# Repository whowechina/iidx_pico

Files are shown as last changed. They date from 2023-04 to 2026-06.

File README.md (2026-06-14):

# IIDX Pico - Beatmania IIDX Style Mini Controller
[点这里可以切换到中文版](README_CN.md)

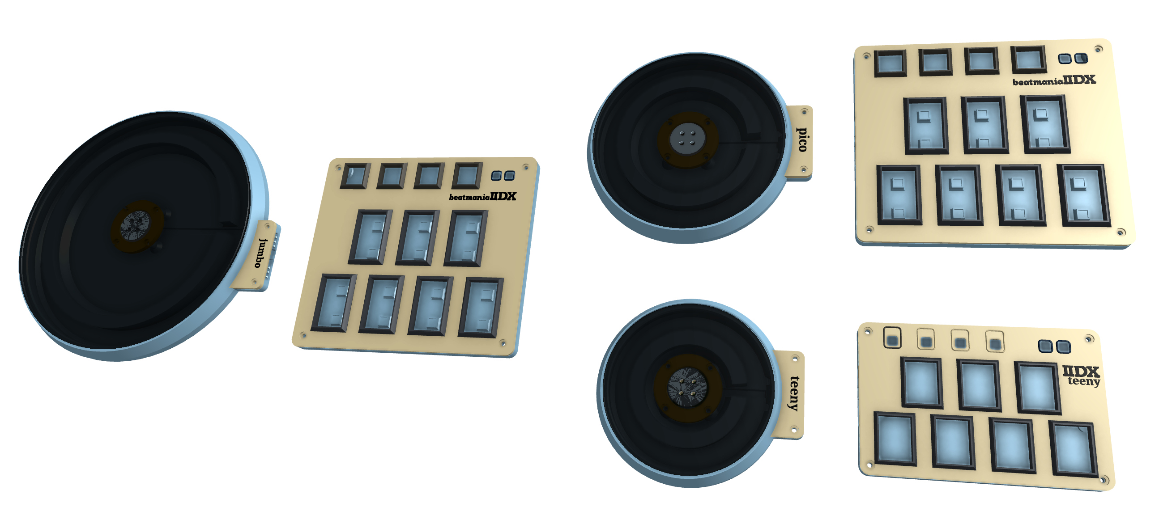
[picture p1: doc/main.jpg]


## Features
* Cool thin design.
* Many variants: IIDX Pico, IIDX Teeny, IIDX Jumbo and IIDX Itsy.
* Foldable with soft hinge.
* Now supports both Hall effect switches and mechanical switches.
* Customizable lights and effects.
* HID lights.
* IIDX Visa card holder.
* All source files open.

## Change Notes
* All IIDX Pico variants have been integrated into this repository for better management.
* The old IIDX Teeny repository has been archived and will be no longer updated.
* Old files have been moved to the Gen1Archive directory, but can also be found in the historical versions.

## Thanks
Thanks to many respectful guys/companies who made their tools or materials free or open source (KiCad, OnShape, InkScape, Raspberry things).

Special thanks to community projects and developers.
And also these projects:
* RP_Silicon_KiCad: https://github.com/HeadBoffin/RP_Silicon_KiCad
* Type-C: https://github.com/ai03-2725/Type-C.pretty

## My Other Projects
You can check out my other cool projects.

               


* Popn Pico: https://github.com/whowechina/popn_pico
* IIDX Pico: https://github.com/whowechina/iidx_pico
* Chu Pico: https://github.com/whowechina/chu_pico
* Mai Pico: https://github.com/whowechina/mai_pico
* Diva Pico: https://github.com/whowechina/diva_pico
* AIC Pico: https://github.com/whowechina/aic_pico
* Groove Pico: https://github.com/whowechina/groove_pico
* Geki Pico: https://github.com/whowechina/geki_pico
* Musec Pico: https://github.com/whowechina/musec_pico
* Ju Pico: https://github.com/whowechina/ju_pico
* Bishi Pico: https://github.com/whowechina/bishi_pico
* Nos Pico: https://github.com/whowechina/nos_pico
* Voltex Pico: https://github.com/whowechina/voltex_pico
* Chord Pico: https://github.com/whowechina/chord_pico
* Dance Pico: https://github.com/whowechina/dance_pico
* Arcade Pico: https://github.com/whowechina/arcade_pico

## **Disclaimer** ##
I made this project in my personal time with no financial benefit or sponsorship. I will continue to improve the project. I have done my best to ensure that everything is accurate and functional, there's always a chance that mistakes may occur. I cannot be held responsible for any loss of your time or money that may result from using this open source project. Thank you for your understanding.

## About the License
It's CC-NC. So DIY for yourself and for your friend, don't make money from it. And plagiarism that doesn’t even dare to mention the original author is not acceptable. Please note that pooling orders and group buying for raw materials is acceptable.Selling any leftover components at cost (without profit) is also acceptable.

If you're interested in buying from me, or for commercial use, please contact me (Discord, QQ group, Goofish).
* My Discord Invitation: https://discord.gg/M8f2PPQFEA
* QQ Group: 854535476
* Goofish: whowe12345

## HOW TO BUILD
### Turntable Materials
* 1x 5mm\*2mm magnet (must be radially magnetized).
* 1x 61804-2RS deep groove ball bearing (20x32x7mm), just choose the cheaper ones.
* 2x 6705-2RS (alternative) deep groove ball bearings (25x32x4mm) for IIDX Jumbo, less wobbling.
* 1x WS2812B LED strip. Go with ones with dense LED configurations. I recommend 80 LEDs per meter or higher for IIDX Pico and IIDX Jumbo; 120 LEDs per meter or higher for IIDX Teeny;
* 1x M2.5*6 screw and hex nut, to fix disc seat, magnet seat and bearing together.
* 4x M3*8mm screws, to fix bearing seat to the base.
* 4x M3*12mm screws, for the disc. 
* 2x M3*8mm screws and hex nuts, for the banner.
* 1x Custom cut black acrylic disc, 3mm thickness for IIDX Pico and IIDX Jumbo.
* Some 10mm non slip self-adhesive silicon pads (also for Keyboard).
* Silicone tube, inner diameter 25mm, outer diameter 27mm, serves as a hinge.
* Some soft ribbon cable with 7 wires, silicone 28AWG is recommended.
* Some acetate cloth tape helps to fix the wires.

### PCB and Keyboard Materials
* 1x Raspberry Pi Pico. If you're building the Itsy, use the "Supermini RP2040 Zero" module instead - it looks like the RP2040 Zero, but has components only on top side.  
  https://www.raspberrypi.com/products/raspberry-pi-pico
* 11x Kailh Choc v1 or v2 key switches, I suggest using linear switches for the 7 main buttons.  
  https://www.kailhswitch.com/mechanical-keyboard-switches/low-profile-key-switches/burnt-orange-switch.html  
  https://www.kailhswitch.com/mechanical-keyboard-switches/key-switches/kailh-low-profile-switch-choc-v2.html
* 7x Kailh 2.0U low-profile stabilizers.  
  https://chosfox.com/products/kailh-1350-choc-switch-6-25u-stabilizer-set
* 2x Panasonic EVQP1K05M square tactile switches for IIDX Pico and IIDX Jumbo.  
  https://www3.panasonic.biz/ac/e/dl/catalog/index.jsp?series_cd=3473&part_no=EVQP1K05M
* 6x Panasonic EVQP1K05M or ALPS SKPMAPE010 square tactile switches for IIDX Teeny.  
  https://www3.panasonic.biz/ac/e/dl/catalog/index.jsp?series_cd=3473&part_no=EVQP1K05M  
  https://tech.alpsalpine.com/e/products/detail/SKPMAPE010/
* 1x USB Type-C socket (918-418K2023S40001 or KH-TYPE-C-16P)
* 1x AS5600 (SOP8), MT6701CT-STD (SOP8), or TMAG5273 (SOT23-6) hall angular sensor chip. For MT6701, trim pin 8 (Z/CSN) if JP1 is not present on the PCB; for AS5600, solder bridge JP1 if it is present.
* RGB LEDs
  * IIDX Pico and IIDX Jumbo (nicer light effect version)
    * 28x WS2812B-1516 or WS2812B-2020 for main buttons, pinout should be exactly like this:  
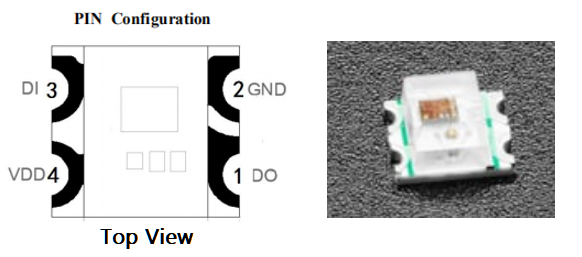
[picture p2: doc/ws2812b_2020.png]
      
    * 4x WS2812B-3528 (or WS2812B-2835), for AUX buttons.
  * IIDX Pico and IIDX Jumbo (easier soldering version)
    * 11x WS2812B-3528 (or WS2812B-2835), forget about ridiculously tiny 28x LEDs.
  * IIDX Teeny
    * 18 WS2812B-3528 (or WS2812B-2835).
* 4x 0603 5.1kohm resistors for USB and I2C.
* 6x 0603 0.1uF capacitors for IIDX Pico and IIDX Jumbo, 4x for IIDX Teeny.
* 4x Kailh low-profile keycaps for IIDX Pico and IIDX Jumbo.
* 4x M3*8mm screws and hex nuts to fix parts together.

### If you want to build Hall Effect version
* WS2812B-3528 per switch is no longer an option. Because it conflicts with the pinout.
* 1x ADG708BRUZ, 8 to 1 analog switch, in TSSOP-16 (U4).
* 1x LP5907MFX-4.5 or TPS7A2042PDBVR LDO, in SOT23-5 (U6), see next line.
* 1x LM4040 shunt voltage reference, get one with 2.0\~2.1V (for 4.2V LDO) or 2.2\~2.5V (for 4.5V LDO) reference voltage, in SOT23-3 (U5).
* 7x SS49E or compatible linear Hall Effect sensors, in SOT23-3 (H1-H7).
* 1x 10ohm resistor, 0603 (R5) and leave R6 absent.
* 1x 3.3V Zener diode, in SOD-123 or SOD-123F, such as BZT52H-C3V3 (Z1).
* 7x low profile magnetic switches, Gateron/NuPhy Jade Mini or Jade Pro Mini, Kailh Star Magnetic Mini, or compatible ones. (SW1-SW7).
* Some more 0.1uF capacitors. (All remaining capacitor positions).
* This shows the soldering for Hall Effect version.  
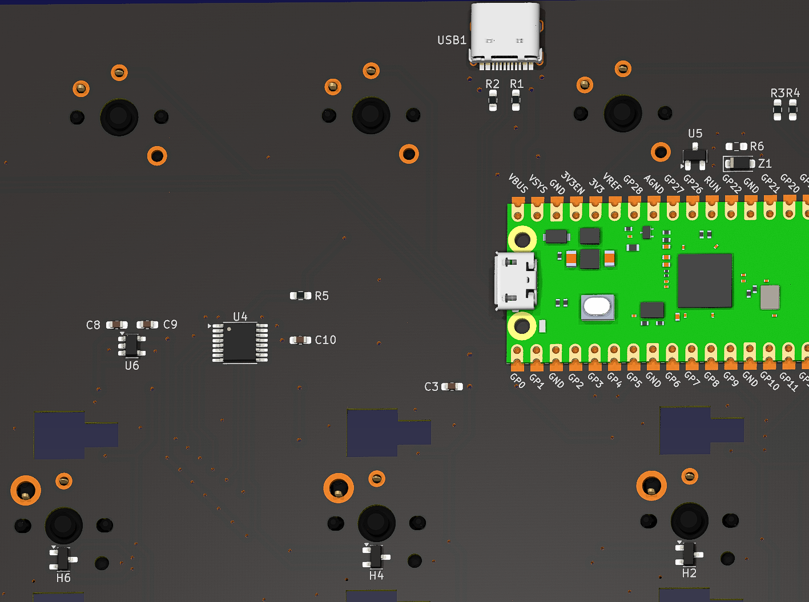
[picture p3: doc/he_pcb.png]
  

### Step 1 - Buy
* Main PCB  
  Just go [JLC](https://jlcpcb.com/) or some other PCB vendor you like and make the order. Make sure the board thickness is **1.2mm**, it's very important!
* Acrylic disc for IIDX Pico and IIDX Jumbo.  
  Find a vendor to cut a 3mm thick black acrylic using corresponding DXF file.  
  You can 3D print a turntable disc, but it is prone to heat deformation.

### Step 2 - 3D Print
#### Keyboard
For following prints, FDM, PLA, 0.4 nozzle, 0.2mm layer.
* Keyboard base ("Keyboard Base *.stl), PLA/PETG transparent, 2 to 3 walls.
* Keyboard panel ("Keyboard Panel.stl"), PLA/PETG transparent, 2 to 3 walls. Please render the panel art and text (height 3mm+) in black if you have multi-color printing system.

#### Turntable 
For following prints, FDM, PLA, 0.4 nozzle, 0.2mm layer, 3 to 4 walls.
* Base ("Turntable \* - Base.stl"), 20-40% infill.
* Bearing seat ("Turntable - Bearing Seat"), 40% to 60% infill.
* Magnet seat ("Turntable - Magnet Seat"), 40% to 60% infill.
* Disc seat ("Turntable - Disc Seat"), 40% to 60% infill.
* For IIDX Teeny only, the disc ("Turntable Teeny - Disc"), 80%+ infill, use a textured PEI bed and concentric pattern for a better surface.
* Banner ("Turntable * - Banner"), 20-40% infill. You can render the text in black if you have multi-color printing system.
* NOTE: IIDX Jumbo with 2 bearings is abbreviated as "Jumbo 2B" in the file name.

#### Button keycaps
* Keycap ("Keycap *.stl", choose the one matches your build), resin printing is recommended, but FDM can work in a pinch.

### Step 3 - Soldering and Assembly Tips
* Keyboard
  * It's very easy to miss two USB pins of the Raspberry Pico Pi, it's at the other side. It's difficult to solder as you may leave air bubbles in the soldering hole. Trick is to use sharpest iron tip, slowly apply solder wire.  
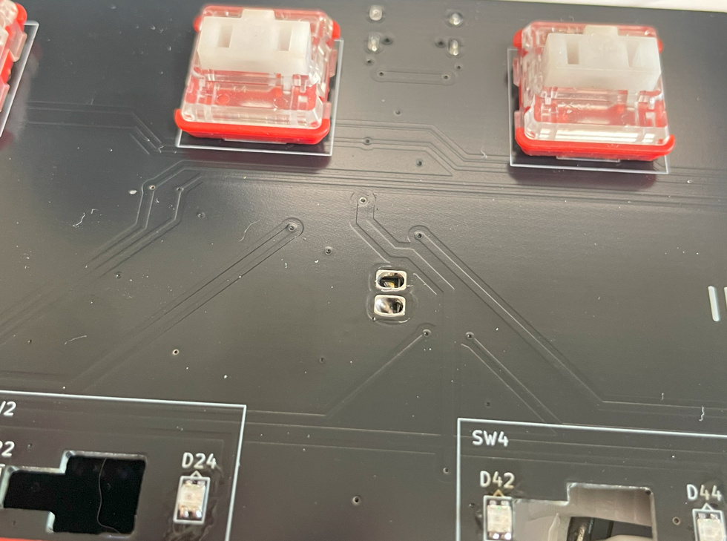
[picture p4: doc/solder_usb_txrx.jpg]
    
  * As long as you have Pi Pico soldered, you can upload firmware and test the board. Please test frequently during the soldering and assembly process.
  * There are two small sensor boards on the main PCB, one for AS5600, the other for TMAG5273. You only need one. After a successful test, you can snap it off for turntable assembly.
  * This gamepad test page can be used for testing. You can move a screwdriver bit on top of the AS5600 or TMAG5273 to see the axis movement.  
    https://greggman.github.io/html5-gamepad-test/
  * Install the low-profile stabilizers.  
    https://docs.keeb.io/choc-stabs  
    A little trick here. Since the PCB footprint is made to support both choc v1 and v2, that leaves some wobble space for choc v1 and making alignment more difficult. So leave the key switch unsoldered, when the stabilizer, the key switch and the keycap are all in place, push the keycap down and then solder the key switch. This way the key switch will be aligned to the stabilizers better.

* Turntable
  * Assembly is pretty straightforward.  
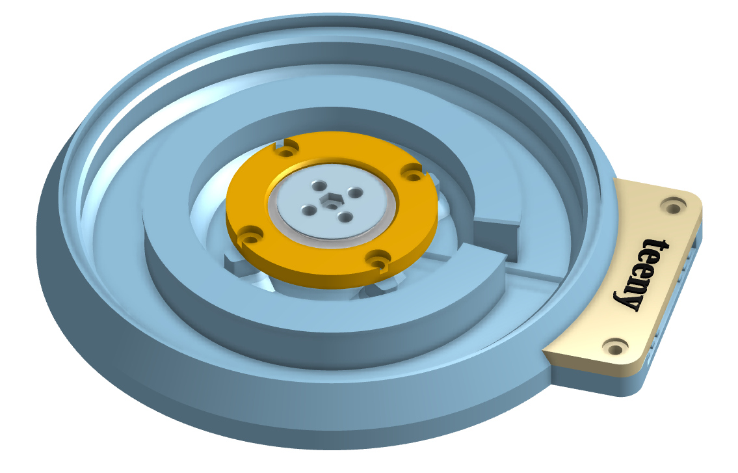
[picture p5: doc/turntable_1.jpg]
      
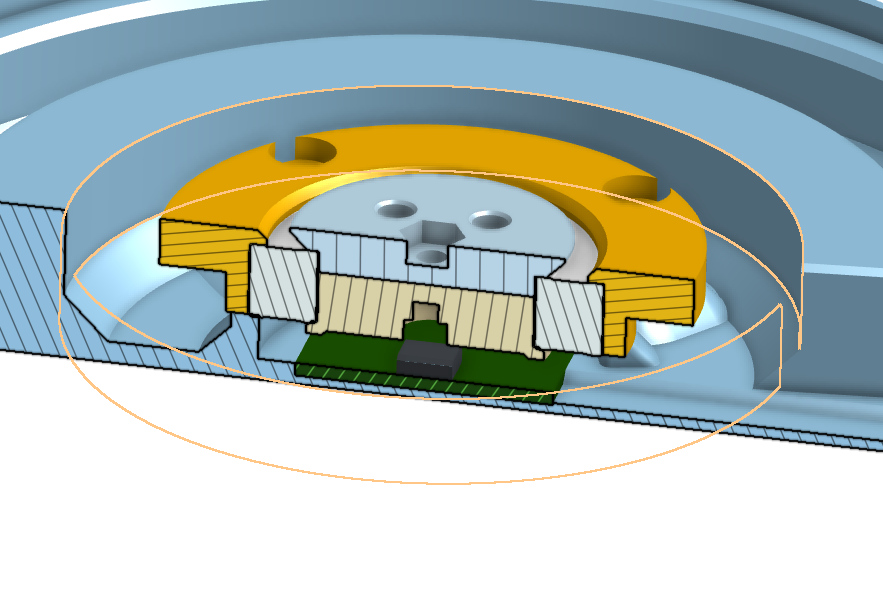
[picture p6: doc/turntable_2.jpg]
    
  * Sensor board is stuck to the base using some thin double-sided tape.
  * For IIDX Jumbo, two 6705-2RS bearings are stacked together.
  * Bearings are originally with very low friction, if you need more resistance, you can add some medium viscosity damping grease, but don't add too much. "2RS" in the bearing model means it's rubber sealed, it's easy to open the rubber seal and add grease.
  * RGB LED strip is stuck to the circular LED wall, both winding directions work.  
  * The 7-wire ribbon cable is for both the RGB LED and the sensor board, 3 for RGB LED, 4 for the sensor board.  
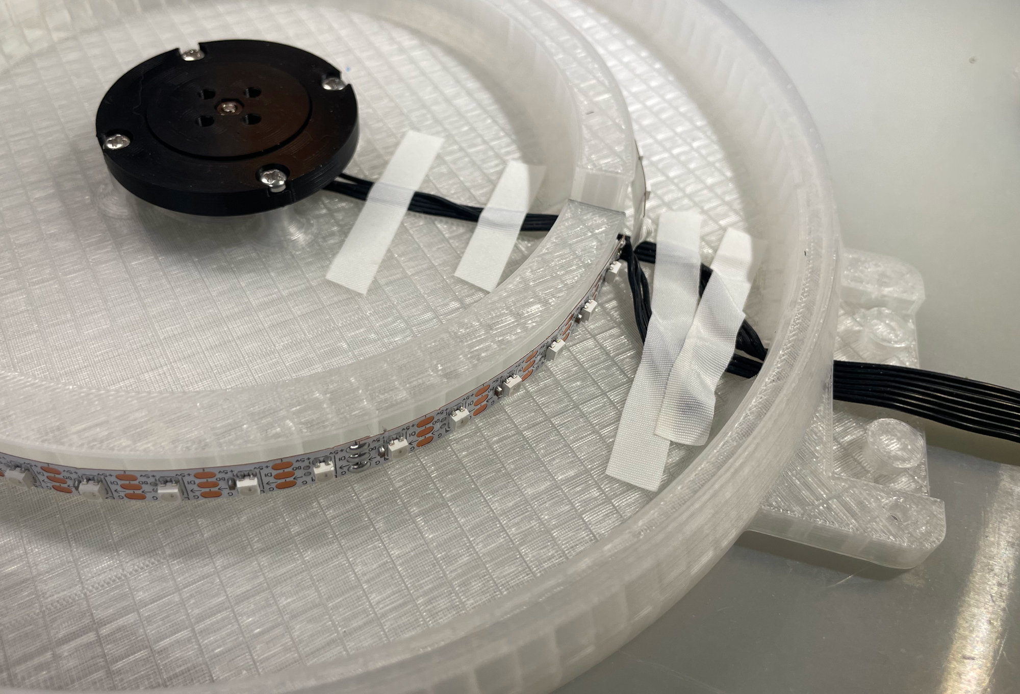
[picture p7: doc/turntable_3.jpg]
    
  * Silicone tube is to connect the turntable and the keyboard. Ribbon cable needs to go through the tube. You need a 7mm or 8mm hole punch to make holes on the silicone tube, to match the hooks at both turntable base and the keyboard sides.

### Notes on Hall Effect version
* For Kailh Star Mini, you need to use 704 RTV silicone adhesive to secure the magnetic switch to the PCB, to prevent it wobbling.
* Calibration must be done in the command line interface.
* Travel distance for triggering and reset can be configured only in the command line interface. They're stored in profile, which means, you can switch between different profiles and have different triggering settings for each profile.

### Firmware
* The UF2 file is in the `Production\Firmware` folder. IIDX Pico/Teeny/Jumbo share the same IIDX Pico firmware.
* For the new build, hold the BOOTSEL button while connect the USB to a PC, there will be a disk named "RPI-RP2" showed up. Drag the UF2 firmware binary file into it and that's it. There's a small hole at the back side of the keyboard, it is facing right to the BOOTSEL button.
* If it is already running my IIDX firmware, hold two small AUX buttons together will do the same as the BOOTSEL button.
* You need to setup your turntable LED strip first, check the manual for the SETUP mode.
* You can set the brightness, turntable LED theme, button LED theme.
* [Nice Looking Manual Here](doc/IIDX_Pico_Manual.pdf)  
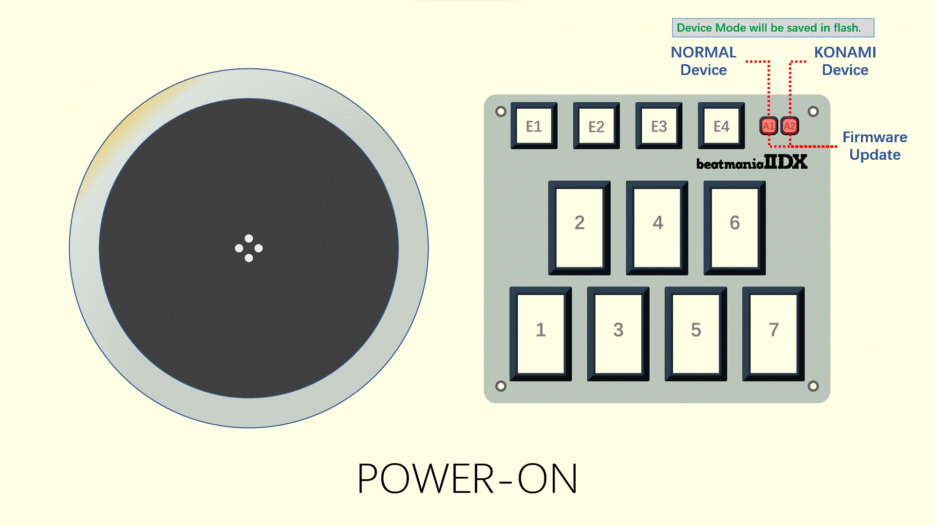
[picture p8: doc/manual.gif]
  

### Tools I Made
* Gamepad test - You can use it to check if all buttons and axes are working correctly.   
  https://whowechina.github.io/iidx_pico/Tools/gamepad_test.html
* Command-line tool - You can access controller's built-in CLI port using this tool.  
  https://whowechina.github.io/iidx_pico/Tools/cli_tool.html

### Bonus - IIDX Visa Card Holder
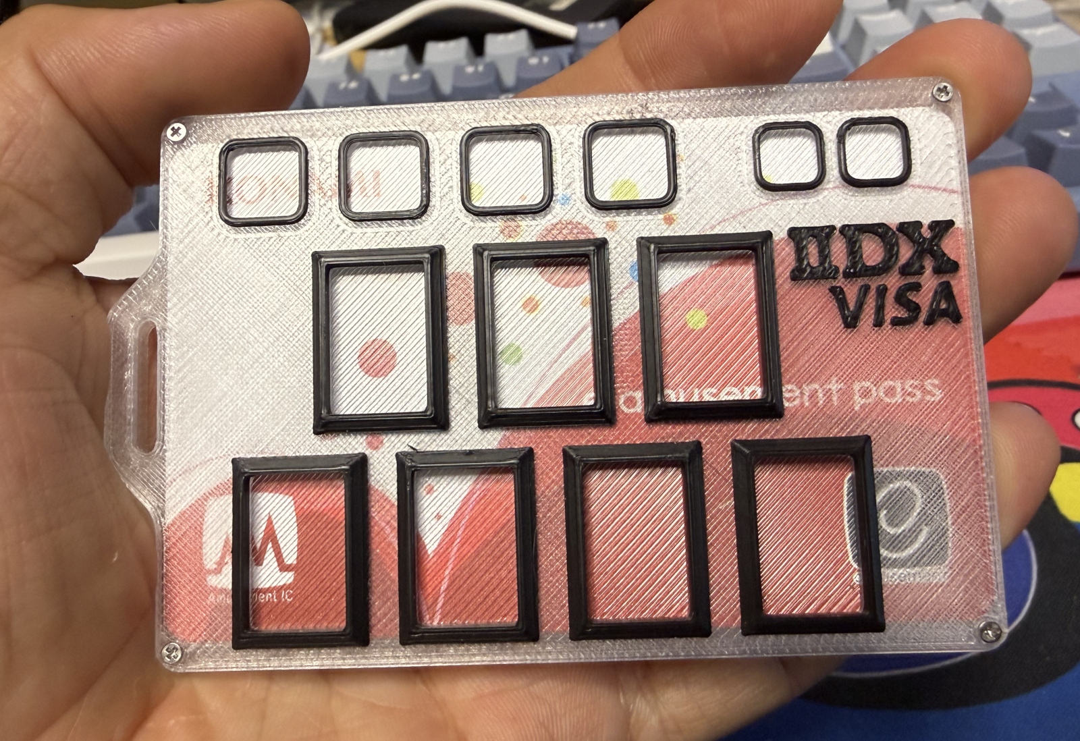
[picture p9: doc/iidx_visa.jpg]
   

* IIDX Visa card holder is a bonus design for IIDX Pico. It can be used to hold your credit card sized arcade cards.
* Print the base and the panel, assign different color for the pattern and text on the panel. `_insert` means it's the heat-set insert version. `_flat` means it's for flat head (countersunk) screws. Transparent material is recommended.
* If you choose the `_insert` version, use 4x M1.2\*1.5mm\*2mm (thread size\*length\*diameter) heat-set inserts on base part.
* 4x M1.2\*3mm screws to fix the panel and the base together. If you choose the `_flat` version, use M1.2\*3mm flat head screws.

## CAD Source File
I'm using OnShape free subscription. It's powerful but it can't archive original designs to local, so I can only share the link here. STL/DXF/DWG files are exported from this online document.  
https://cad.onshape.com/documents/ed99bfa5b4aec5d3ea6e6ed6/w/9a87f8b714078597b4ef5e3c/e/2e27bace5a421a921473c027

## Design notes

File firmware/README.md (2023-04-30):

# IIDX Pico Firmware

Features:
* 1000Hz polling rate.
* HID lights.
* RGB turntable.
* Configuration save.
* Customizable through board_defs.h
* Dymanic settings.

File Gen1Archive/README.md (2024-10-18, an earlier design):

# IIDX Pico - Beatmania IIDX controller

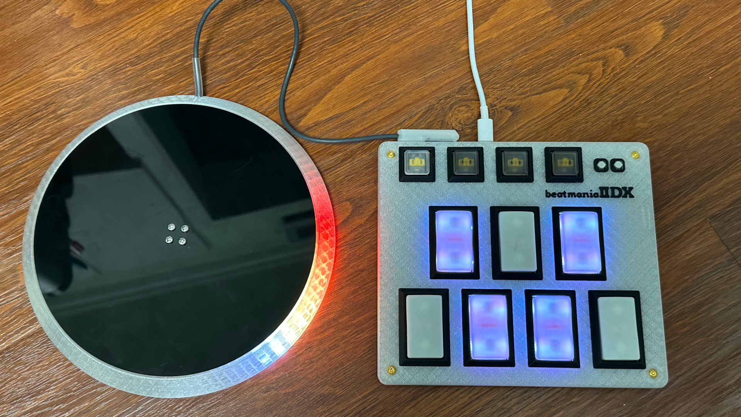
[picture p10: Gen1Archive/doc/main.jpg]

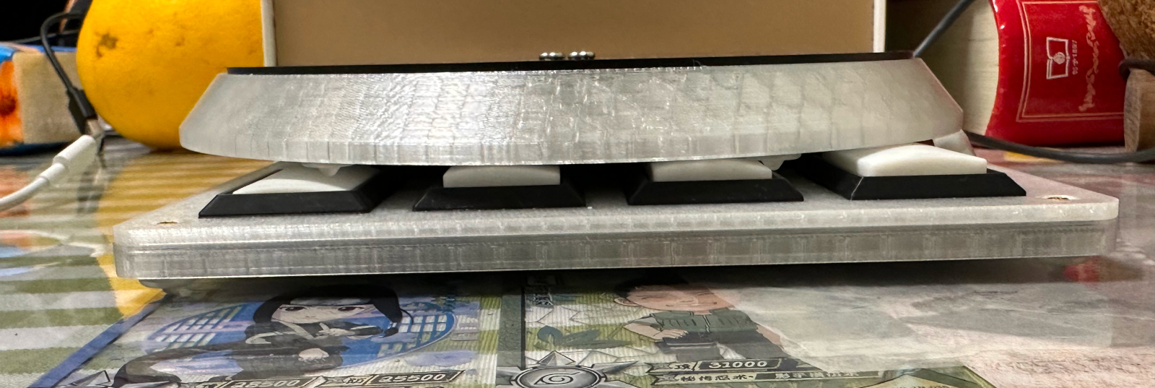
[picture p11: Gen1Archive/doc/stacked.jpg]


<video src="https://user-images.githubusercontent.com/11623830/229287886-d01893c5-04b6-41fc-a178-72c815e28c96.mp4" controls="controls" width="50%"></video>

Features:
* It's thin, really thin.
* Detachable turntable using magnetic connector (soft hinge is another option).
* HID lights, of course!
* Key color theme and customization.
* Multiple turntable effects.
* Many live settings.
* Konami device mode for IIDX Ultimate Mobile.
* All source files open.

Thanks to many respectful guys/companies who made their tools or materials free or open source (KiCad, OpenSCAD, InkScape, Raspberry things). And also:
* RP_Silicon_KiCad: https://github.com/HeadBoffin/RP_Silicon_KiCad
* Switch_Keyboard_Kailh: https://github.com/kiswitch/keyswitch-kicad-library
* Type-C: https://github.com/ai03-2725/Type-C.pretty

## Notes
This is a difficult build, it heavily depends on 3D printing, both FDM and SLA (resin). It also requires skills to solder tiny components and thin cables., much more difficult than my other projects such as Pico Popn.

Move forward only if you're REALLY interested.  

## My Other Projects
You can check out my other cool projects.

         

* Popn Pico: https://github.com/whowechina/popn_pico
* IIDX Pico: https://github.com/whowechina/iidx_pico
* IIDX Teeny: https://github.com/whowechina/iidx_teeny
* Chu Pico: https://github.com/whowechina/chu_pico
* Mai Pico: https://github.com/whowechina/mai_pico
* Diva Pico: https://github.com/whowechina/diva_pico
* AIC Pico: https://github.com/whowechina/aic_pico
* Groove Pico: https://github.com/whowechina/groove_pico
* Geki Pico: https://github.com/whowechina/geki_pico
* Musec Pico: https://github.com/whowechina/musec_pico

## **Disclaimer** ##
I made this project in my personal time with no financial benefit or sponsorship. I will continue to improve the project. I have done my best to ensure that everything is accurate and functional, there's always a chance that mistakes may occur. I cannot be held responsible for any loss of your time or money that may result from using this open source project. Thank you for your understanding.

## About the License
It's CC-NC. So DIY for yourself and for your friend, don't make money from it. And plagiarism that doesn’t even dare to mention the original author is not acceptable. Plase note that pooling orders and group buying for raw materials is acceptable. Selling off any leftover components without profit is also acceptable.

If you're interested in some kind of commercial use, please contact me (Discord, QQ group, Wechat group or leave your contact in issue section).

## My Discord Invitation
https://discord.gg/M8f2PPQFEA

## HOW TO BUILD
### Turntable Materials
* 1x AS5600 hall angular sensor board set (23mm\*23mm)  
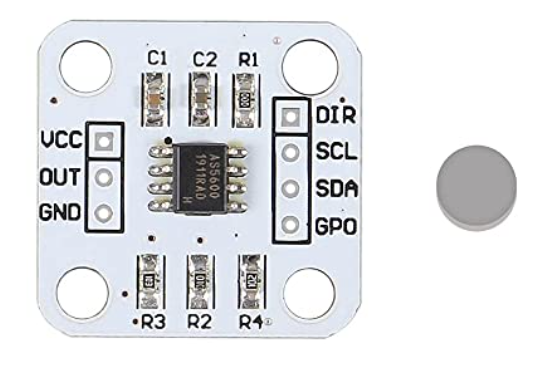
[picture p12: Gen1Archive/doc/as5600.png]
  
* 1x 6mm\*2mm magnet (must be radially magnetized), normally comes with the AS5600 board set.
* 1x 61804-2RS deep groove ball bearing (20x32x7mm), normally < 5US$;
* 1x WS2812B LED ring board, or RGB LED strip (recommended). Choose ones with dense LED arrangement (>=32 LEDs per board, or >90 LEDS per meter);
* 3x M4*10mm screws (large flat head is better) and hex nuts, for bearing. For hinge version, use M3 screws.
* 4x M3*12mm screws, for spinning disc. 
* 1x REF3030 (3.0V Voltage Reference, SOT-23-3).
* 1x Custom cut black acrylic disc, 4mm thickness.
* 11x 12mm non slip self-adhesive silicon pads (also for Keyboard).  
  https://www.amazon.com/Cabinet-Dampening-Adhesive-Circular-Stoppers/dp/B07XXWG818

### Keyboard Materials
* 1x Raspberry Pi Pico.  
  https://www.raspberrypi.com/products/raspberry-pi-pico
* 11x Kailh Choc v1 or v2 key switches, to get better play feel, 7 of them should be 50g linear.  
  https://www.kailhswitch.com/mechanical-keyboard-switches/low-profile-key-switches/burnt-orange-switch.html  
  https://www.kailhswitch.com/mechanical-keyboard-switches/key-switches/kailh-low-profile-switch-choc-v2.html
* 7x Kailh low-profile stabilizers.  
  https://chosfox.com/products/kailh-1350-choc-switch-6-25u-stabilizer-set
* 2x Panasonic 6mm square tactile switch EVQP1K05M.  
  https://www3.panasonic.biz/ac/e/dl/catalog/index.jsp?series_cd=3473&part_no=EVQP1K05M
* 1x USB Type-C socket (918-418K2023S40001 or KH-TYPE-C-16P)
* 11x WS2812B-3528 RGB LEDs or if you want more challenge: 28x WS2812B-1516.
* 2x SN74LV1T34DBVR (SOT-23-5) level shifter, optional, for better voltage tolerance.
* 2x 0603 10ohm resistors to bypass said level shifters, optional.
* 1x 0603 5.1kohm resistors for USB.
* 5x 0805 1uF capacitors.
* 4x Kailh low-profile keycaps.
* 4x M3*6mm screws and hex nuts to fix parts together.

### Detachable Cable
* 1x HDMI cable (ultra slim, diameter < 4mm), at least 50cm in length, we'll cut the HDMI connectors off, so pick a cheap one.
* 2X Magnetic pogopin connector sets, male and female. PCB side should use ones with 90-degree pins, cable side use ones with straight pins.  
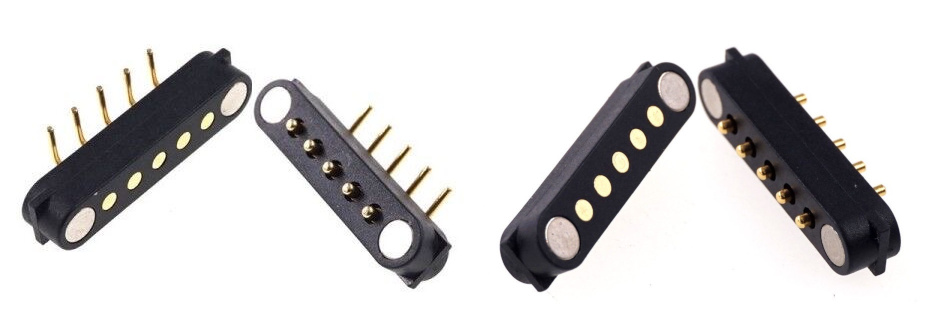
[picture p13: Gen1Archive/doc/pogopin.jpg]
  

### Step 1 - Buy
* Keyboard PCB  
  Just go [JLC](https://jlcpcb.com/) and make the order. Make sure the board thickness is **1.2mm**, it's very important!
* Turntable PCB  
  It's an optional one. It makes the wiring and soldering inside the turntable a litter easier.
* Acrylic disc  
  Choose the dxf file according to your disc size and find a vendor to cut the 4mm black acrylic.

### Step 2 - 3D Print
#### Keyboard
* PCB bottom (pcb_bottom_*.stl, choose one according to your connector or hinge choice)  
  FDM, PLA/PETG transparent, 0.2mm layer, 4 walls.
* PCB top (pcb_top.stl)  
  FDM, PLA transparent, 0.2mm layer, 4 walls.  
  If you have Bambu Lab's AMS system, use PLA black/gray for 3.0mm+ layers.

#### Turntable 
For following prints, FDM, PLA, 0.4 nozzle, 0.16-0.2mm layer, 4 walls.  And very important: "Seam Position" should be set to "**Random**" in your slicer, not only it looks better, it makes the bearing-flange coupling smoother and tension distributed more evenly.  
These are all printed with
* Base (TT_base_xxx.stl), choose one of the 150, 170 or 180, based on your choice of disc size, 20-60% fill.
* Bearing seat (bearing_seat_6804.stl), 20-60% fill.
* Flange for disc (TTshaft_6804.stl), 60% fill.
* If you opt for the hinge option, go with the files with "hinge" in the filename.

#### Pogopin Connector
It's very small and requires higher accuracy.
* Housing for pogopin connector (pogo_bottom.stl, pogo_top.stl).  
  FDM, PLA, **0.2 nozzle** is recommended, 0.1mm layer, 4 walls, 60% fill.

#### Button keycaps  
  * Option 1 (Choc V1 or V2): SLA (resin), regular white, 0.05mm layer, check out my orientation:  
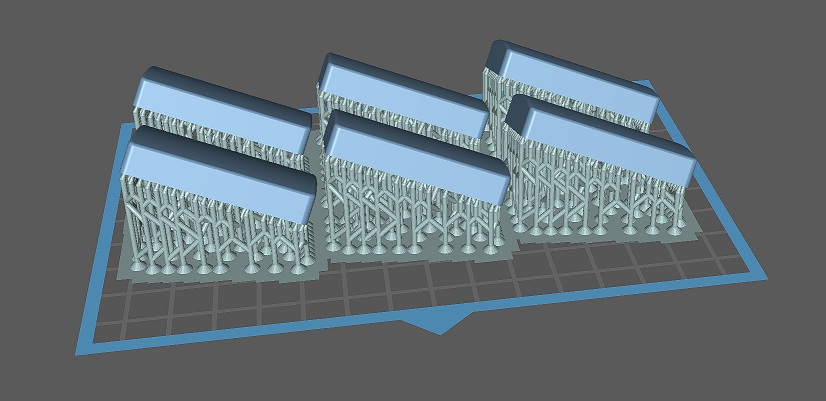
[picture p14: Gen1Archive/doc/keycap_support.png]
    
  * Option 2 (Choc V2 only): FDM, PLA white, 0.2mm nozzle recommended but 0.4mm nozzle works too, 0.10~0.16mm layer, use easy-to-remove material for support, like "Bambu Support W" or just PETG.  
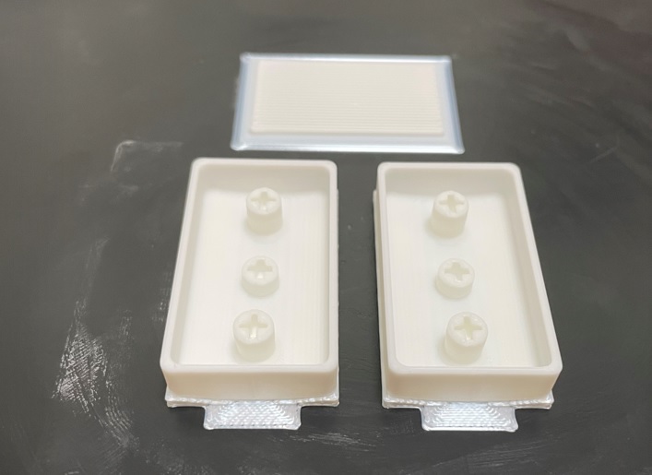
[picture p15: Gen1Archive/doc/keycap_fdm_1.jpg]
    
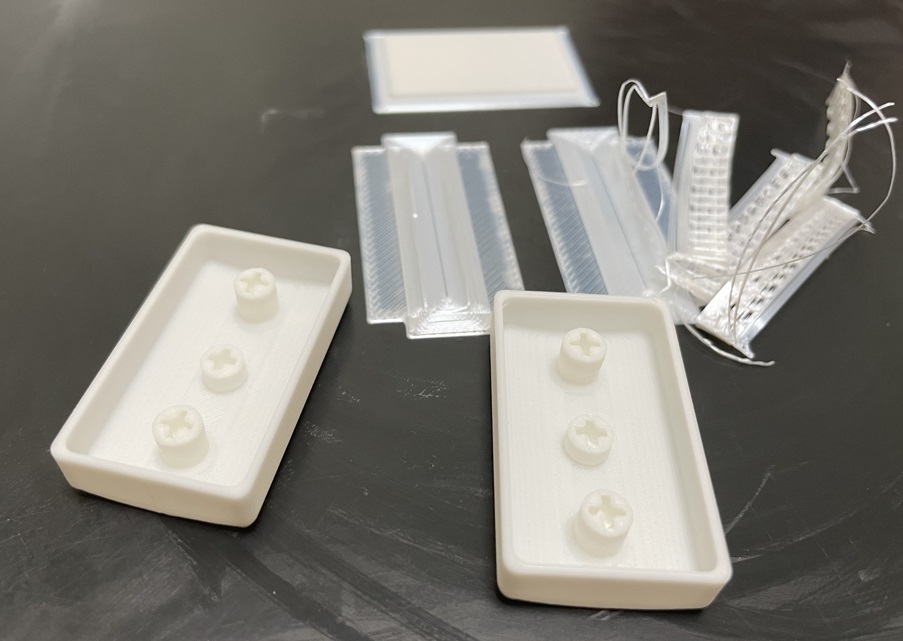
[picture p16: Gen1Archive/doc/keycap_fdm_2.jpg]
    

### Step 3 - Solder
* Keyboard  
  * WS2812 choices for main 7 main keys, for each key: solder 1x WS2812B-3528 under the key switch, or 4x WS2812-1516 around the key switch.
  * IMPORTANT: be careful about the orientation of LEDs, they're different at different rows or columns.  
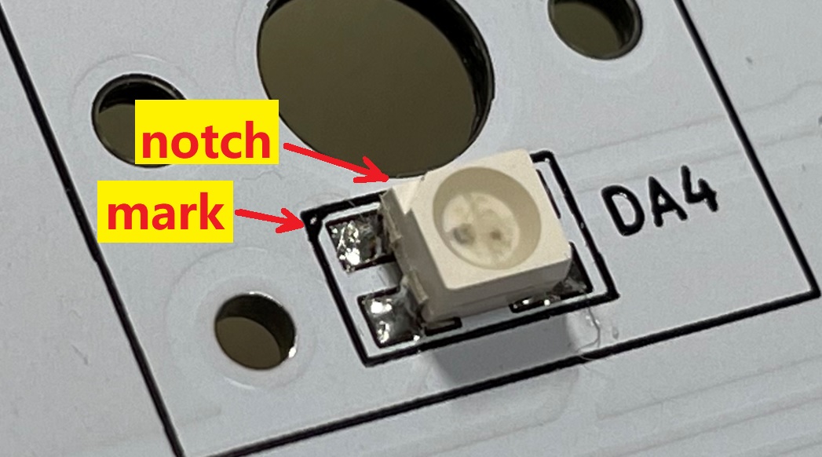
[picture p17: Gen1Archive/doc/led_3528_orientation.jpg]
    
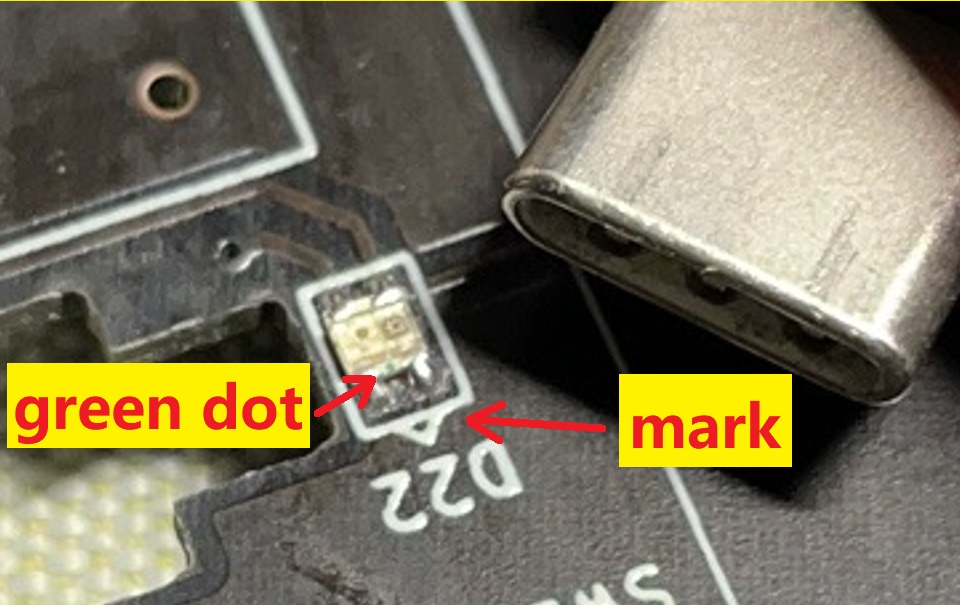
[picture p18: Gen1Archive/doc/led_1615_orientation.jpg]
    
  * Connector choices: solder 2x pogopin connectors, or solder 1x 3.5mm headphone input jack.
  * It's very easy to miss the USB pins of the Raspberry Pico Pi, it's at the other side. And it's difficult to solder as you may leave an airbubble in the soldering hole. My trick is to use sharpest iron tip, super-slowly apply solder wire only at one side. This is my result:  
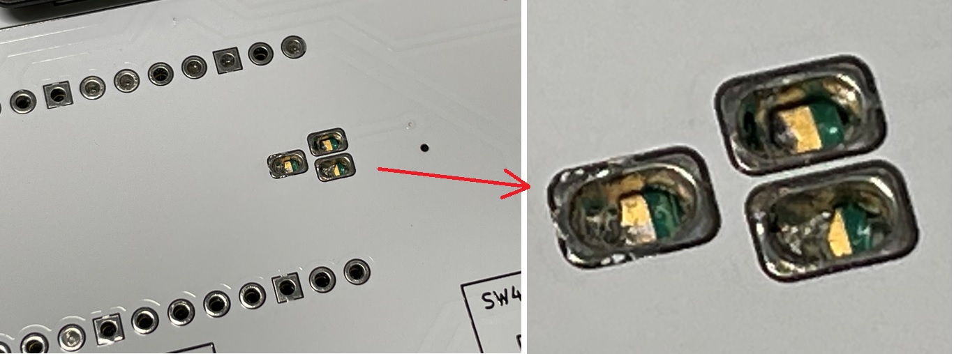
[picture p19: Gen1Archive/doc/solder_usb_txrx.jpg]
    

  * You can use level shifter (SN74LV1T34DBVR, U2/U3), or you can just bypass it by soldering a nearby resistor (10 ohm, R1/R2).
  * Optional: TVS1 and TVS2 are rated 3.3V, protecting GPIOs. TVS3 should be rated 5V when using level shifter, and 3.3V when not using level shifter.
* Turntable
  * General  
  Typical AS5600 development board comes with 3.3V configuration, we can't feed 5V to it directly, it would burn the AS5600 or the main Pi Pico. The GPIO we use to communicate with AS5600 can never go beyond 3.6V. So we need a lower voltage, I chose REF3030, a precise 3.0V voltage reference.  
  You need to scrape off some solder mask to expose the ground copper (don't scrape the solder mask under 5V pin). I found a good place to mount the REF3030, this is how I handled it:  
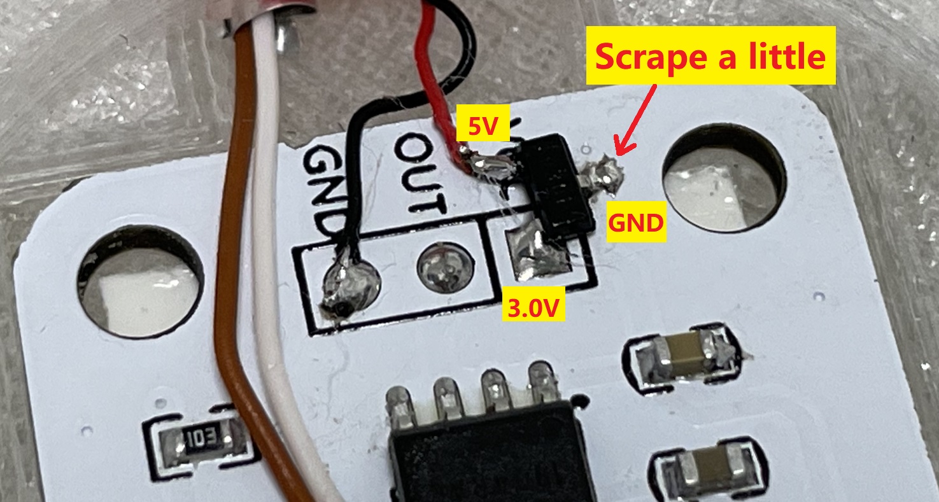
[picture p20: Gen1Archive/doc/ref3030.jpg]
    

  * **Very Important**  
  Before proceeding further, it's important to know that the silicone hinge option used in my IIDX Teeny has proven to be the most effective and stable. Therefore, it's highly recommended to opt for the hinge option, rather than the subsequent digital (pogopin). I've also removed the analog (3.5mm headphone jack) option simply because it's not good. If you use Teeny's silicone hinge option, use the added J3/J4 3.3v soldering pads to power the AS5600.

  * If you go with digital (magnetic pogo pin connector)  
  There're a set of I2C and a WS2812B signal line together in the cable that connects turntable and the keyboard. Unfortunately, these signals crosstalk. So, we have to use shield cables for them. Two I2C lines should have a shield cable, and the WS2812B signal should have another shield cable. Good thing is, an HDMI cable has 4 shield cables and bunch of other small cables. We can make use of it.  
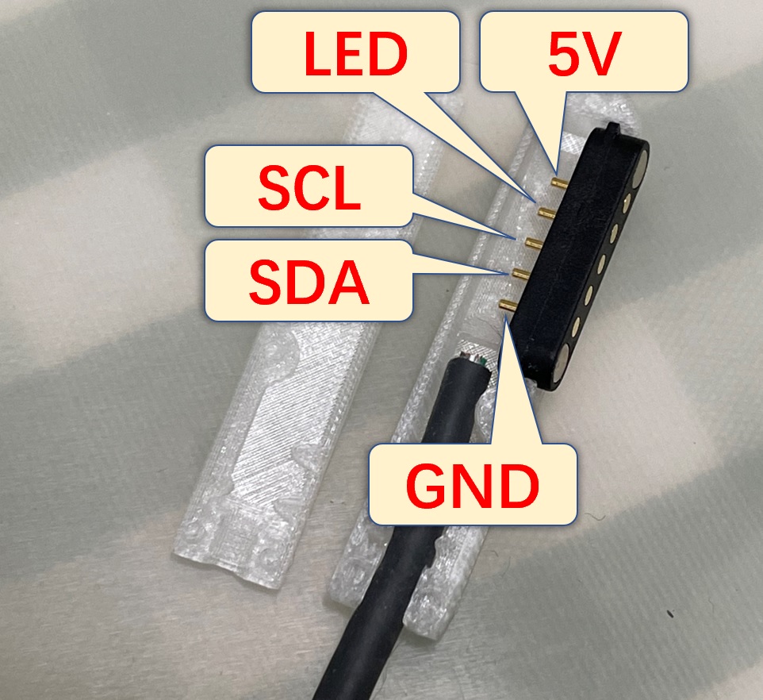
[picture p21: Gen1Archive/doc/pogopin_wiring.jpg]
      

* Turntable LED Ring  
  I recommend to use LED strip over LED board, becuase the LED board's light is facing up, but using strip, the light can spread out pefectly.  
  Use transparent double-sided tape to stick the LED around the turntable inner wall.

### Step 4 - Assemble
* Assemble the turntable  
  I don't know how to draw an explosion diagram, this is done by coding in OpenSCAD:  
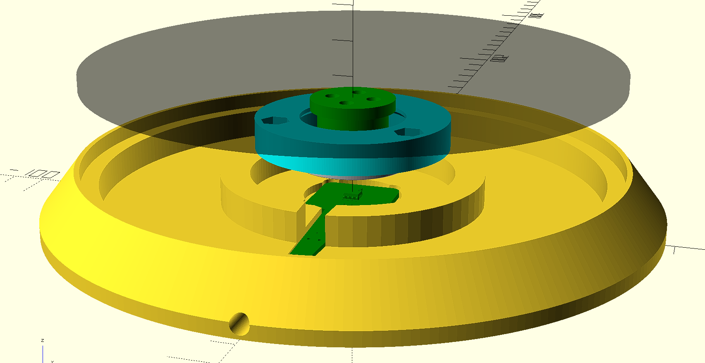
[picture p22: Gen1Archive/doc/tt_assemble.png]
    
  These shows how a bearing is installed.  
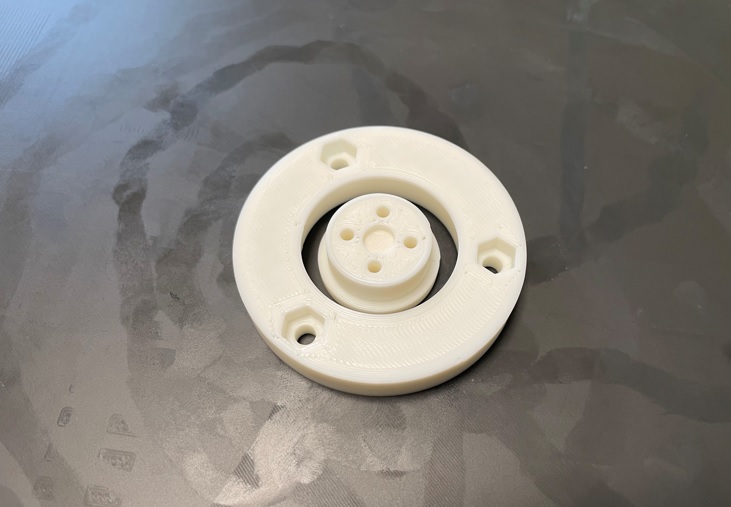
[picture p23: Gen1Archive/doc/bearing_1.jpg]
  
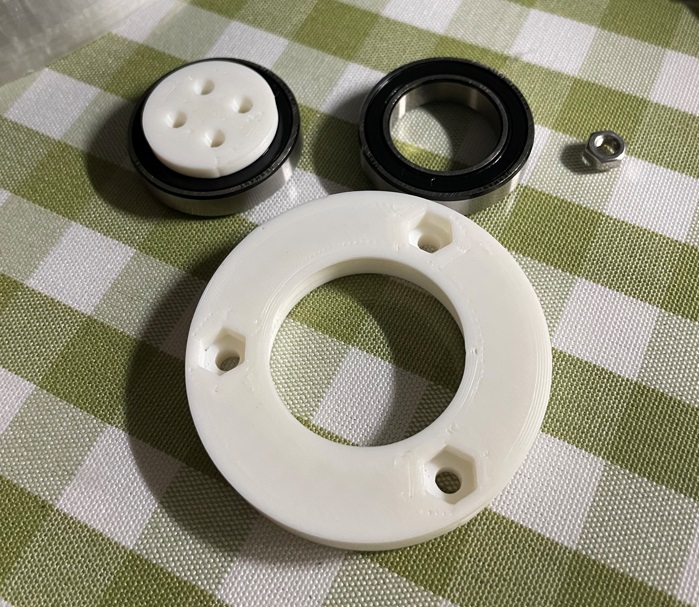
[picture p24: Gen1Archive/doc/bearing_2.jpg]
  
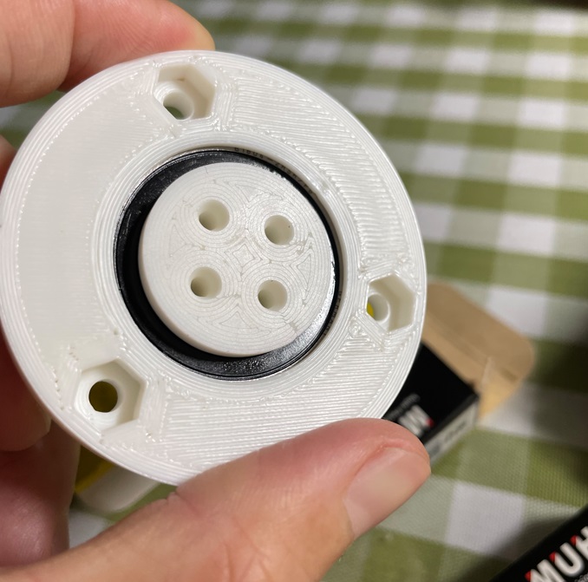
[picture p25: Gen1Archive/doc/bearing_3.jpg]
  
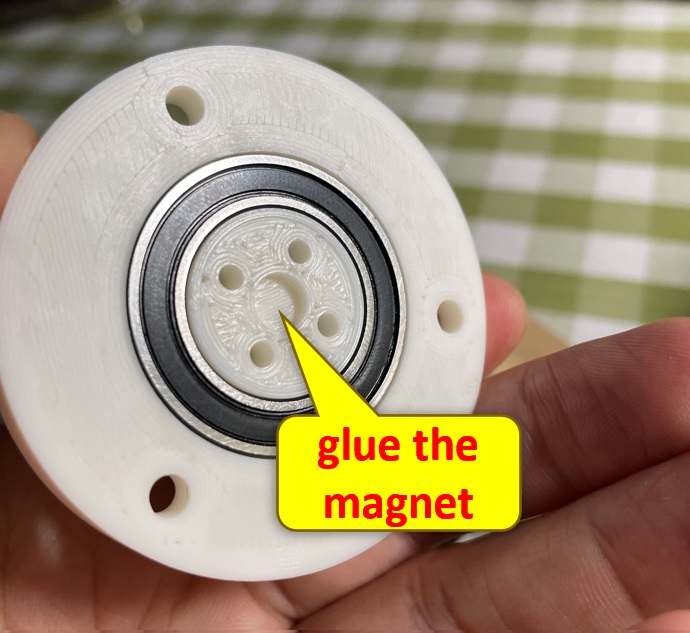
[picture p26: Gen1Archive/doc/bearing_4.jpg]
  
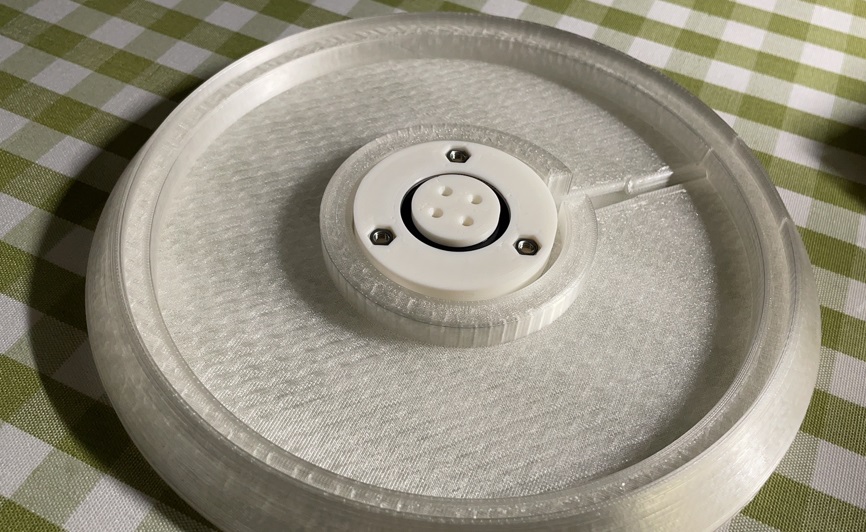
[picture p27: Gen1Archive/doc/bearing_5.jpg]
  

* Install the low-profile stabilizers.  
  https://docs.keeb.io/choc-stabs  
  A little trick here. As the PCB footprint is made to support both choc v1 and v2, that leaves some wobble space for choc v1 and makes it difficult to align. So leave the key switch unsoldered, when the stabilizer, the key switch and the keycap are all in place, push the keycap down and then solder the key switch. This way the key switch will be aligned to the stabilizers better.

  **VERY IMPORTANT**

  I made a terrible mistake in early PCBs which causes main buttons sticky (not physically responsive as expected). If you're using PCB v1.3 or later version, you're fine. If you're using PCB v1.2 or earlier version, there's a simple fix. Just manually cut some bevelling on the PCB, so stabilizer's shaft can move freely. You need to do all the buttons. Please don't cut through the PCB, just cut the edge a little at the bottom.  
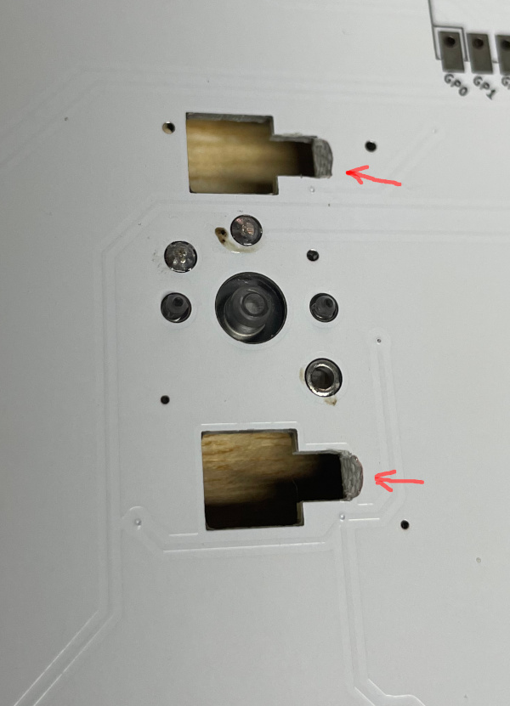
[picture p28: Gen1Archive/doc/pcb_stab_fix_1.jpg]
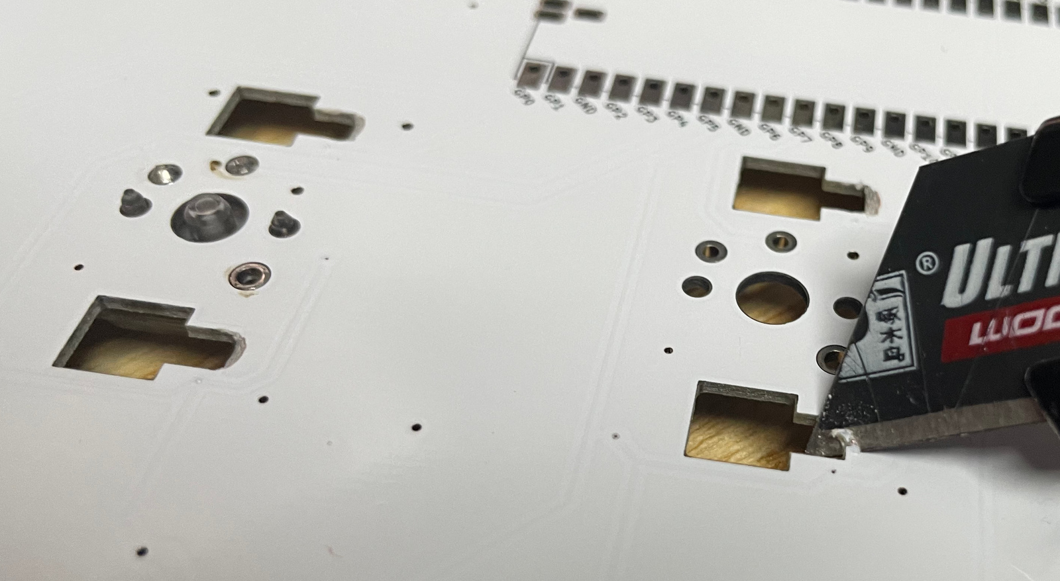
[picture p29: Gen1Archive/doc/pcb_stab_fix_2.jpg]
   

* Assemble the keyboard  
  It's very easy.  
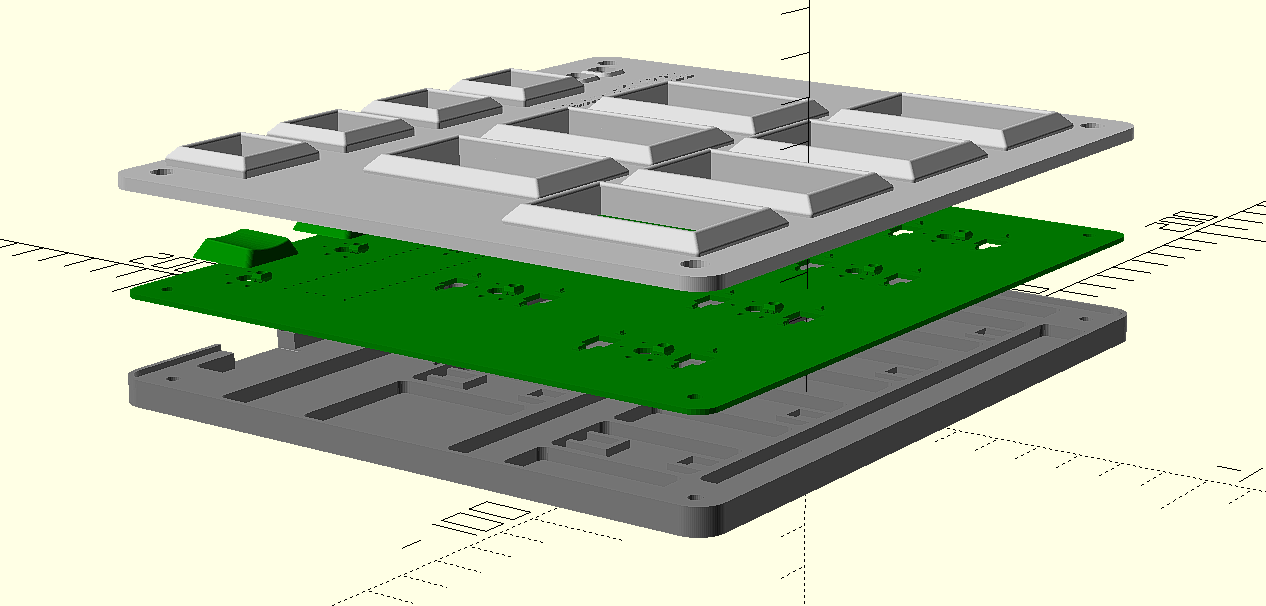
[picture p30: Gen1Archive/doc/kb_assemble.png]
    
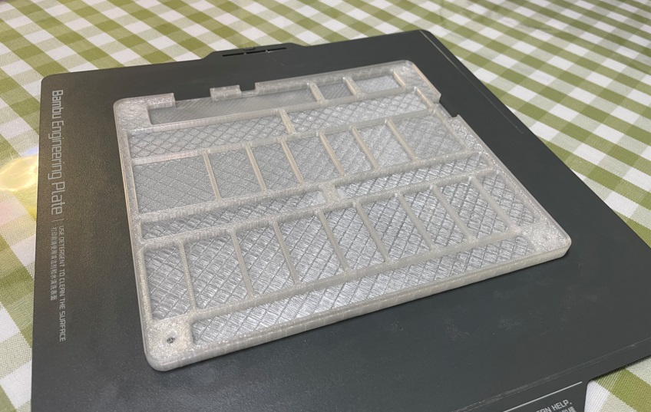
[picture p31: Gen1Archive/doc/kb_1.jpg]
  
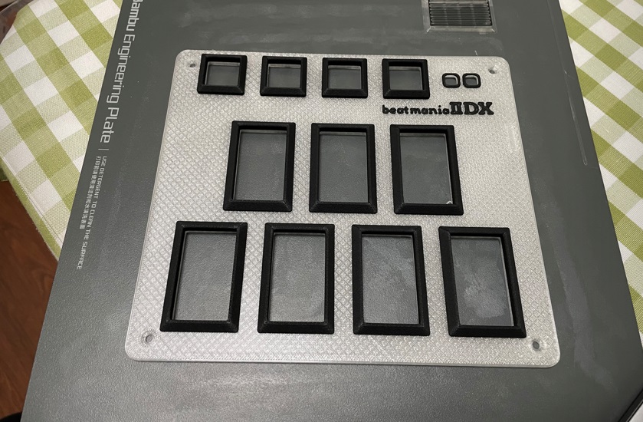
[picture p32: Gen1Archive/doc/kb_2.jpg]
  
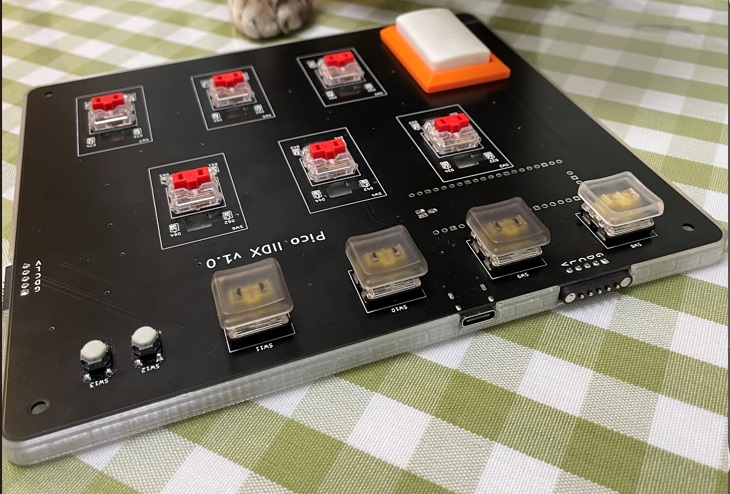
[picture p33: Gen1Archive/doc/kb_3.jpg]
  
  
  

### Step 4 - Firmware
* For the new build, hold the BOOTSEL button while connect the USB to a PC, there will be a disk named "RPI-RP2" showed up. Drag the uf2 firmware binary file into it. That's it. There's a small hole at the back side of the keyboard, it is facing right to the BOOTSEL button.
* If it is already running my IIDX firmware, hold two small AUX buttons together will do the same as the BOOTSEL button.
* You need to setup your configuration such as AS5600 connection mode and LED ring.
* Also you can setup the key color theme and turntable effects at runtime. I think I made the configuration too showey and complicated. Check out the manual.   
  [Nice Looking Manual Here](doc/Firmware_manual.pdf)
  

### What If?
* I can't find pogopin connector.  
**Solution:** I figured out some another choices, one is using a 3.5mm 4P headphone jack. It uses analog to communicate turntable movements, but I'm still testing it, so stay tuned. I will update this document. The other is to use fixed connection (left or right hinge).
* I don't have Bambu Lab's machine, or I don't have an AMS system.  
**Solution:** There're many online vendors and people providing paid Bambu printing service. Or you can just use other 3D printers. It's just the numbers in the OpenSCAD source file or STL files are finetuned on my Bambu Lab X1. You may need to adjust a little on your 3D printer system to get perfect result. And regarding the multi-color thing, maybe you can just paint the top layer by hand. I know people do miniature painting, I think it would be similar.
* STL files are not accurate, difficult to assemble.  
**Solution:** 3D printer systems are different one from another, it results in small differences even with same model file and some configuration. If the printed parts are not happy with each other, you can fiddle with the OpenSCAD source file and the numbers in it for your case.
* I don't have resin printer.
* I can't find Kailh low-profile stabilizer.
* I don't have electronic DIY gears.  
**Solution:** OK, this is an electronic hobby project, maybe it's not for you if you don't plan to do electronic DIYs. There're many good IIDX controllers you can purchase somewhere online.
* I want Bluetooth support.  
**Not A Solution:** I once wanted to implement the Bluetooth support. But after I tried bluetooth joystick, I gave up. You really don't want to play rhythm game with a Bluetooth connection!

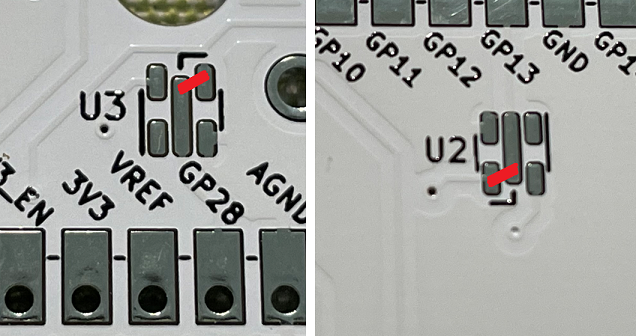
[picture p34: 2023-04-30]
doc/bypass_level_shifter.png

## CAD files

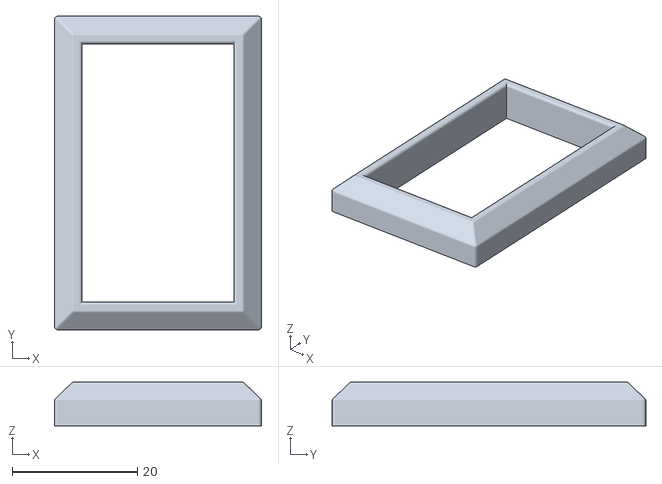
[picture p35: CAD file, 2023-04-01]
cad/keycap_frame_main.stl
33.0 x 50.0 x 7.00

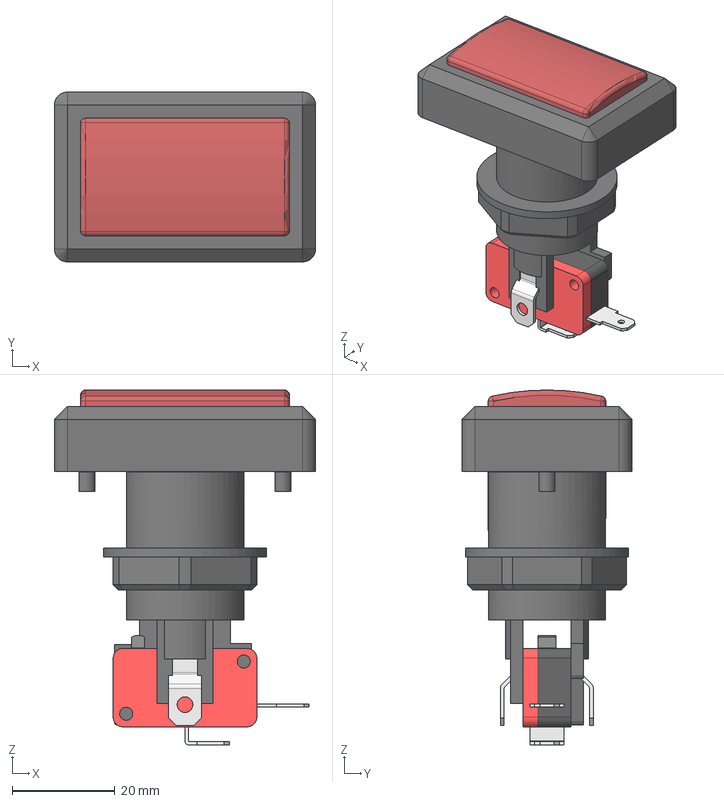
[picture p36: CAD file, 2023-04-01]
PCB/Itsy/3dmodels/Credit Button Assy (Groovy).step
50.8 x 33.0 x 69.0 mm
Button
Nut
Switch

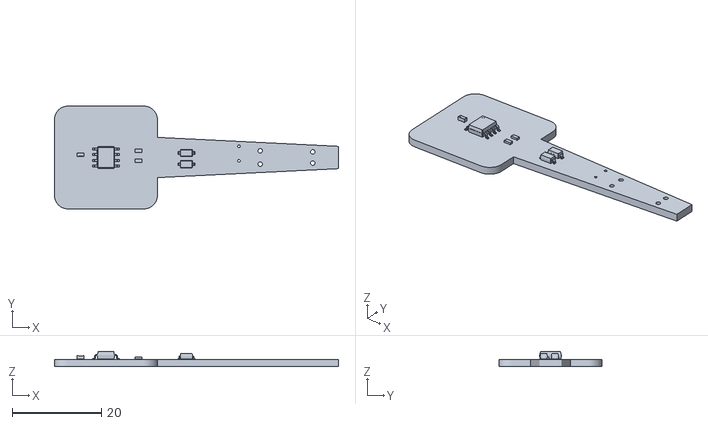
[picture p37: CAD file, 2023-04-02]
cad/iidx_tt v1.stl
63.5 x 23.0 x 3.40

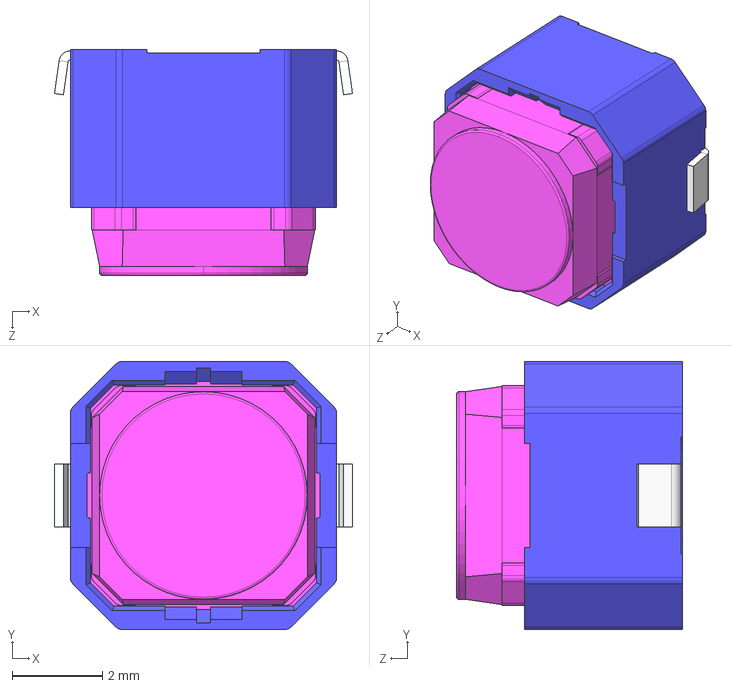
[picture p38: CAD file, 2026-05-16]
PCB/Itsy/3dmodels/SKPMAM.STEP
6.60 x 5.94 x 5.00 mm

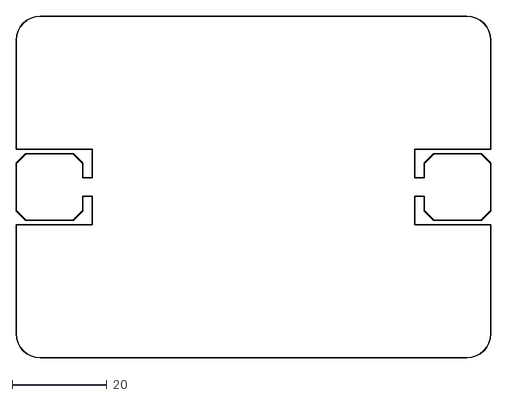
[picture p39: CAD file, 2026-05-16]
PCB/Itsy/Keyboard Itsy - Itsy PCB.dxf
100.0 x 72.0

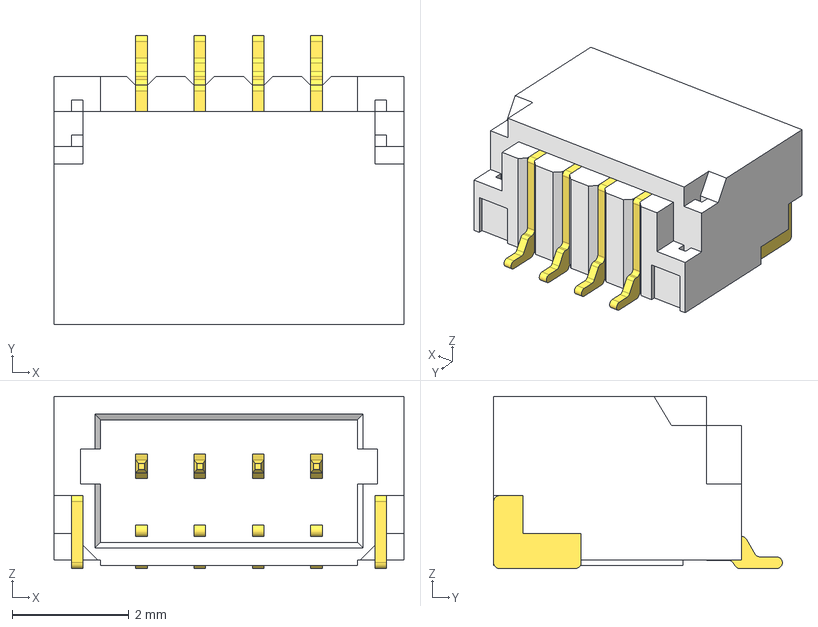
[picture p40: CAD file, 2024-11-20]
PCB/Pico/3dmodels/SM4B-SRSS-TB.step
6.00 x 4.95 x 2.95 mm

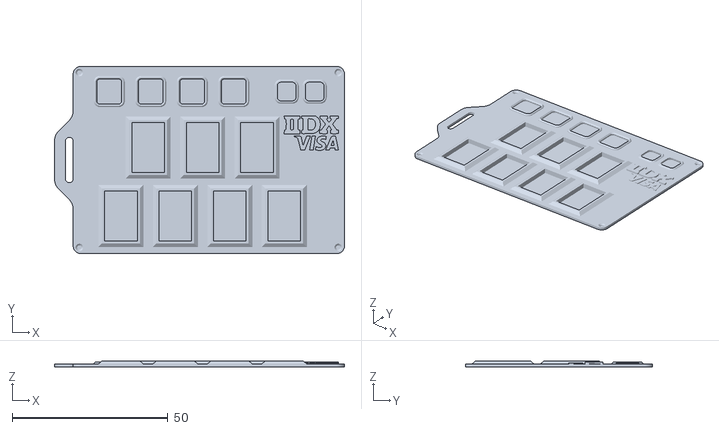
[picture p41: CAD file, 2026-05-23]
Production/3DPrint/IIDX Visa - Panel_Flat.stl
93.2 x 60.2 x 2.00

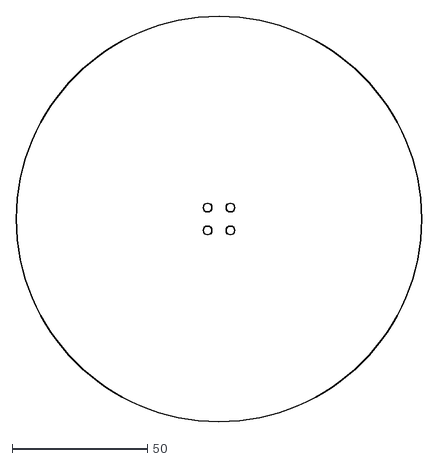
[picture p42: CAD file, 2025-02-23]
Production/AcrylicCut/Turntable Pico - Disc.dxf
150.0 x 150.0

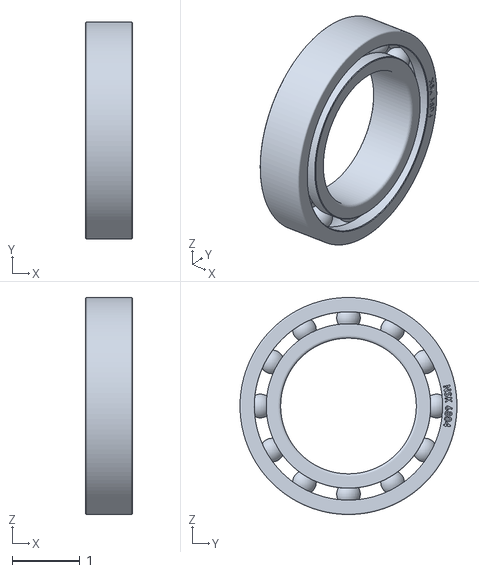
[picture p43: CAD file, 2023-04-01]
cad/nsk6804.stl
0.7 x 3.20 x 3.20

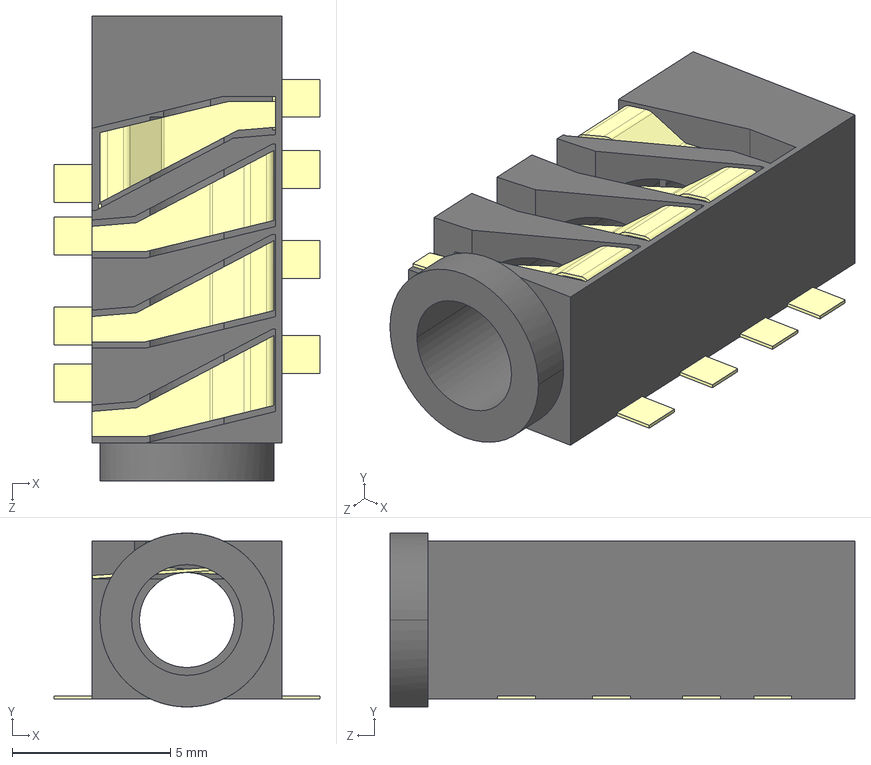
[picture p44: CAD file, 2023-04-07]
PCB/Itsy/3dmodels/User Library-pj-393-8.STEP
8.40 x 5.50 x 14.7 mm
PJ-393-8_1
PJ-393-8_2 x 4
PJ-393-8_3
PJ-393-8_4 x 3

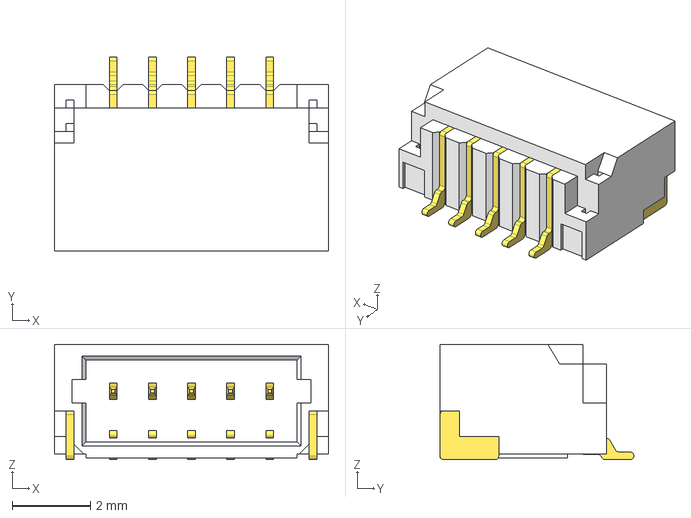
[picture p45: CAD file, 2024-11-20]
PCB/Pico/3dmodels/SM5B-SRSS-TB.step
7.00 x 4.95 x 2.95 mm

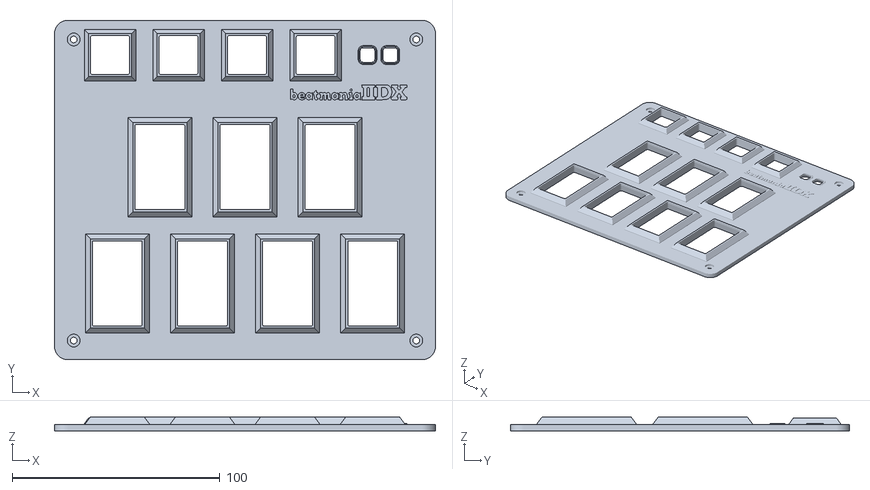
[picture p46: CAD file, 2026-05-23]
Production/3DPrint/Keyboard - Panel.stl
183.5 x 163.5 x 6.60

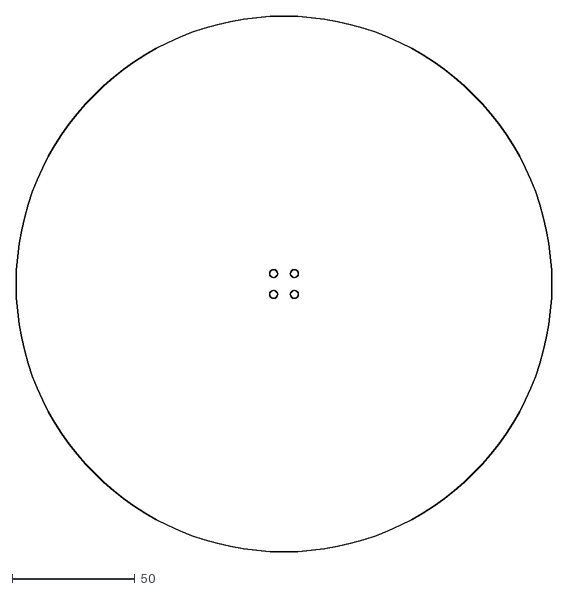
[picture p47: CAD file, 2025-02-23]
Production/AcrylicCut/Turntable Jumbo - Disc.dxf
218.0 x 218.0

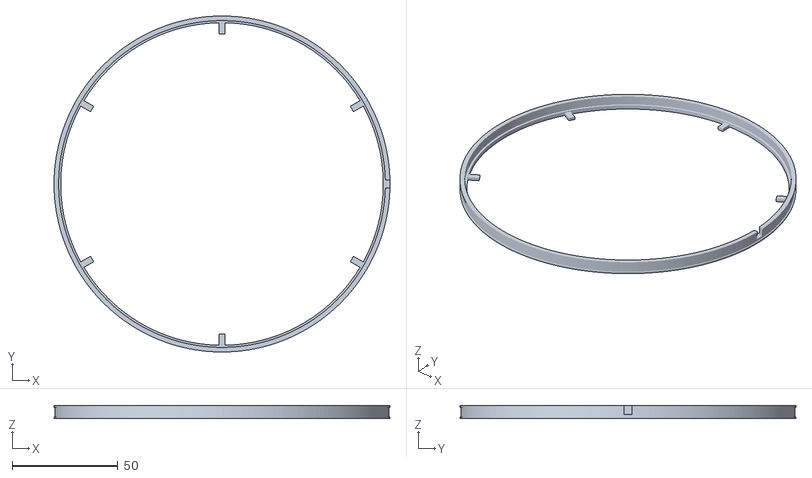
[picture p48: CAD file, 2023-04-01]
cad/tt_led_ring_180.stl
159.0 x 159.0 x 6.18

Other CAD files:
PCB/Itsy/3dmodels/iidx_keycap_main_step.stp
PCB/Itsy/3dmodels/WS2812B.step
PCB/Pico/3dmodels/SM3B-SRSS-TB.step
Production/3DPrint/IIDX Visa - Base.stl
Gen1Archive/cad/bearing_seat.scad
Gen1Archive/cad/iidx_keycap_main.scad
Gen1Archive/cad/kb_assemble.scad
Gen1Archive/cad/keycap_frame.scad
Gen1Archive/Production/3DPrint/TT_base_150.stl
Gen1Archive/Production/3DPrint/TT_base_170.stl
Gen1Archive/Production/3DPrint/TT_base_180.stl
Gen1Archive/Production/3DPrint/TT_base_hinge_150.stl
Gen1Archive/Production/3DPrint/TT_base_hinge_170.stl
Gen1Archive/Production/3DPrint/TT_base_hinge_cover_150.stl
Gen1Archive/Production/3DPrint/TT_base_hinge_cover_170.stl
Gen1Archive/Production/3DPrint/TTshaft_6804.stl
Gen1Archive/Production/3DPrint/TTshaft_6805.stl
Gen1Archive/Production/3DPrint/bearing_seat_6804.stl
Gen1Archive/Production/3DPrint/bearing_seat_6804_hinge.stl
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

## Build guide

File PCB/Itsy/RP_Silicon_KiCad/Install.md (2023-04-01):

# Install KiCad libraries

## Manage Symbol Libraries

Accessed from the Preferences menu, add a new line with the +, give it a name and use the folder icon to point to the directory/folder where you have KiCadLibraries.

Manage Symbol Libraries screen shot


## Manage Footprint Libraries

Ditto! Accessed from the Preferences menu, add a new line with the +, give it a name and use the folder icon to point to the directory/folder where you have KiCadLibraries.

Manage Footprint Libraries screen shot


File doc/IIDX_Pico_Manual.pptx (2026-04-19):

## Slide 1

English

https://github.com/whowechina/iidx_pico

Manual for
IIDX Pico/Teeny/Jumbo

## AT POWER-ON

NORMAL Device

Device Mode will be saved in flash.

KONAMI
Device

Factory Reset

Firmware
Update

## NORMAL MODE

Profile 2

TT
Effect

Switch Profiles

Enter
LED LEVEL
Mode

Hold 5 Seconds

Enter
SETUP
Mode

Profile 1

Profile 3

Key Off
Light

Profile 4

Key Release

Choose Function

Key
Theme

Key On
Light

Key Trigger

## LED LEVEL MODE

Turntable

Buttons

17%

Level means maximum brightness.
Level for turntable and buttons are separate.

LED Level

OK

Cancel

50%

83%

0%

33%

67%

100%

1-7 Quick Set

## SETUP MODE

Normal Reversed

LED
Direction

LED Select

Set First LED

Set Last
LED

Buttons

Sensor
Mode

E1~E4

Normal
Reversed
LR2

OK

Cancel

Turntable

LED Color
Format
GRB/RGB

256/200
ppr

160/128
ppr

96/64
ppr

48/32
ppr

Turntable Resolution

## Set Key On/Off Light

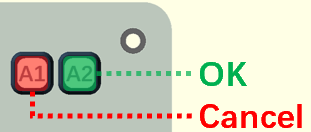
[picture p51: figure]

2. Set Saturation (Vividness )

1. Set Hue
(Color)

3. Set Value (Brightness)

Start

Confirm

Select Keys to Apply
(Toggle during the process)

## Set Key Trigger/Release Distance

Note: Hall effect version only.

Set Distance

Start

Select Keys to Apply

## Hall Effect Sensor Calibration

Note: Hall effect version only.

- When you feel the triggering is not right, you may need a calibration.
- Sensor calibration can only be performed through CLI (Command-Line Interface).
- You need a serial terminal tool to access the CLI, such as this online one: https://googlechromelabs.github.io/serial-terminal/
- Once in the CLI, follow the steps to calibrate:
  - Enter "calibrate" command.
  - Press all 7 keys randomly, make sure all keys are covered.
  - Done.

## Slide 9

中文

https://github.com/whowechina/iidx_pico

IIDX Pico/Teeny/Jumbo
操作手册

## 上电时

设备模式会存储在 flash 里。

恢复
出厂设置

普通设备

KONAMI 设备

固件更新

## 一般模式

配置 2

转盘
灯效

进入
LED 亮度设置模式

切换配置槽

按压 5 秒

进入
基础设定
模式

配置 1

配置 3

松键
灯光

配置 4

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
## LED 亮度设置模式

转盘

按键

17%

亮度是指全局最大亮度。
转盘和按键的亮度可以分开设置。

LED
亮度调整

确认

取消

50%

83%

0%

33%

67%

100%

1-7 快捷设置

## 基础设定模式

正常 反向

LED
方向

LED 设置

设置首个 LED

设置末尾
LED

按键

传感器
模式

E1~E4

正常
反向
LR2 专用

确认

取消

转盘

LED
像素格式
GRB/RGB

256/200
ppr

160/128
ppr

96/64
ppr

48/32
ppr

转盘分辨率

## 设置按键 On/Off 灯光

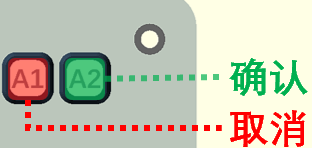
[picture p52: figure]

2. 设置灰度
(色彩饱和度)

1. 设置色度 (颜色)

3. 设置明度 (亮度)

开始

完成确认

选择需要应用的键
(设置过程中随时切换)

## 设置霍尔按键触发和恢复行程

注意：仅霍尔版本支持。

设置行程

开始

选择需要应用的键

## 霍尔传感器校准

注意：仅霍尔版本支持。

- 当你感觉触发不正确时，可能需要校准。
- 传感器校准只能通过 CLI（命令行界面）执行。
- 你需要一个串口终端工具来访问 CLI，比如这个在线工具： https://googlechromelabs.github.io/serial-terminal/
- 进入 CLI 后，按照下面步骤进行校准：
  - 输入 "calibrate" 命令。
  - 随机按压所有 7 个按键，确保所有按键都被按到。
  - 完成。

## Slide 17

한국어

https://github.com/whowechina/iidx_pico

IIDX Pico/Teeny/Jumbo
사용 설명서

## 전원 인가 시

장치 모드는 flash 에 저장됩니다.

공장 초기화

일반 장치

KONAMI 장치

펌웨어 업데이트

## 일반 모드

설정 2

턴테이블 조명 효과

진입
LED 밝기 설정 모드

프로필 전환

5 초간 누르세요

진입
기본 설정 모드

설정 1

설정 3

키 해제 시 조명

설정 4

리셋 거리

설정 항목 선택

키패드 조명 효과

키 입력 시 조명

트리거 작동 거리

## LED 밝기 설정 모드

턴테이블

버튼

17%

LED
밝기 조정

밝기는 전체 최대 밝기를 의미합니다.
턴테이블과 버튼의 밝기는 각각 따로 설정할 수 있습니다.

확인

취소

50%

83%

0%

33%

67%

100%

1-7 빠른 설정

## 기본 설정 모드

일반 반전

LED
방향

LED 설정

첫 번째 LED 설정

마지막 LED 설정

키패드

센서 모드

E1~E4

일반
반전
LR2 전용

확인

취소

턴테이블

LED
픽셀 포맷
GRB/RGB

256/200
ppr

160/128
ppr

96/64
ppr

48/32
ppr

턴테이블 해상도

## 버튼 On/Off 조명 설정

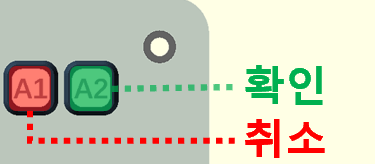
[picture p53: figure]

2. 채도 설정

1. 색상 설정

3. 명도 설정

시작

완료 후 확인

적용할 키를 선택하세요
(설정 중 언제든지 전환할 수 있습니다)

## 홀 키 트리거 및 리셋 거리 설정

주의: 홀 효과 버전만 지원

거리 설정

시작

적용할 키 선택

## 홀 센서 캘리브레이션

주의: 홀 효과 버전만 지원

- 트리거링이 올바르지 않다고 느껴질 때 캘리브레이션이 필요할 수 있습니다.
- 센서 캘리브레이션은 CLI(명령줄 인터페이스)를 통해서만 수행할 수 있습니다.
- CLI 에 접근하려면 시리얼 터미널 도구가 필요합니다. 다음 온라인 도구를 사용하세요： https://googlechromelabs.github.io/serial-terminal/
- CLI 에 진입한 후, 아래 단계에 따라 보정하세요:
  - "calibrate" 명령을 입력하세요.
  - 7개 키를 모두 무작위로 눌러서 모든 키가 눌렸는지 확인하세요.
  - 완료.

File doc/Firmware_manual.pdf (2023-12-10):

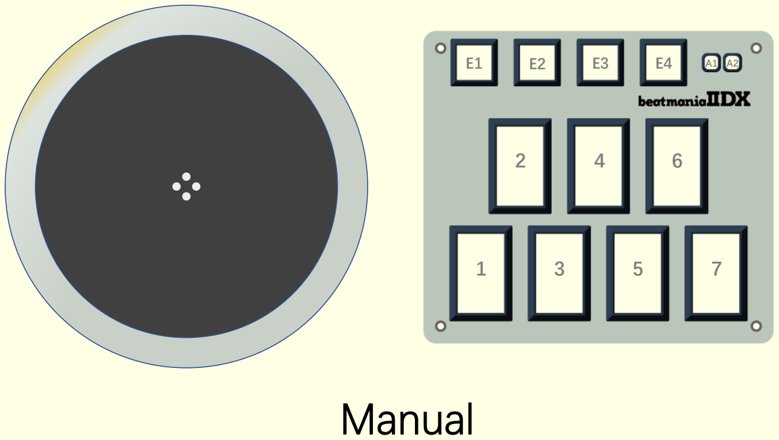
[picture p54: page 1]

1 | 3 | 5 | 7
2 | 4 | 6
E1 | E2 | E3 | E4 | A1 A2

# Manual

# POWER-ON

NORMAL
Device

Firmware
Update

KONAMI
Device

Device Mode will be saved in flash.

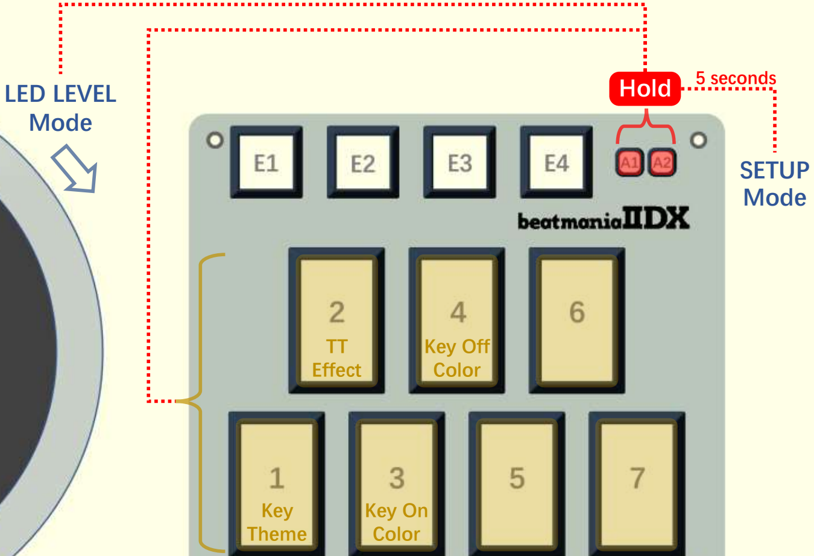
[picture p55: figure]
Hold; SETUP Mode; 5 seconds; TT Effect; Key Off Color; Key Theme; Key On Color; LED LEVEL Mode

# NORMAL MODE

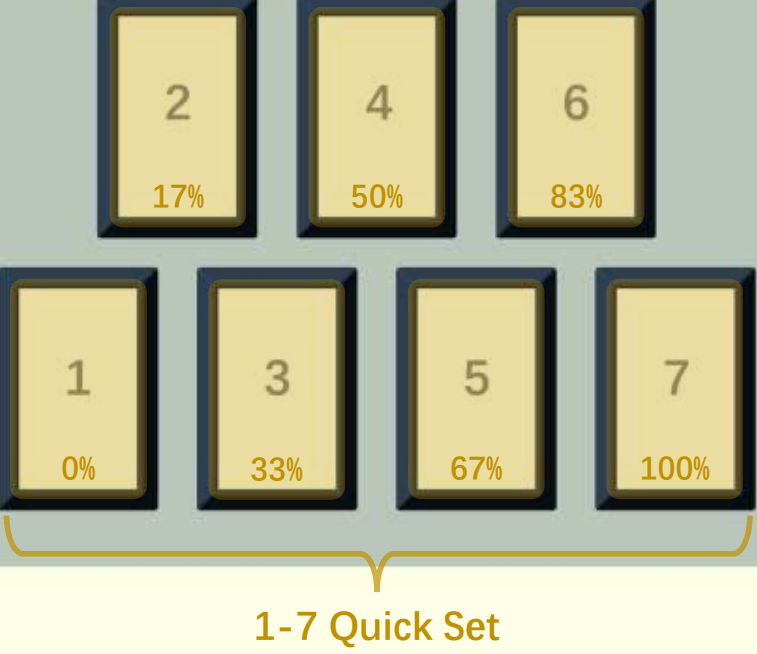
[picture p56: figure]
1-7 Quick Set

# LEVEL MODE

OK

LED Level

Cancel

Overall LED Brightness Level

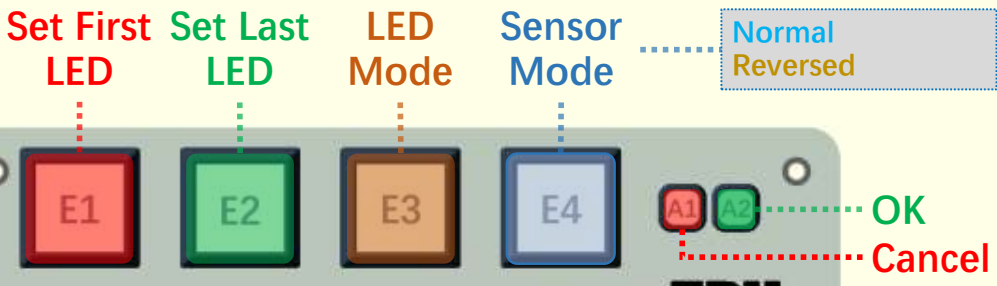
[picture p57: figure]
OK Cancel; Set First LED; Set Last LED; LED Mode; Sensor Mode; Normal Reversed
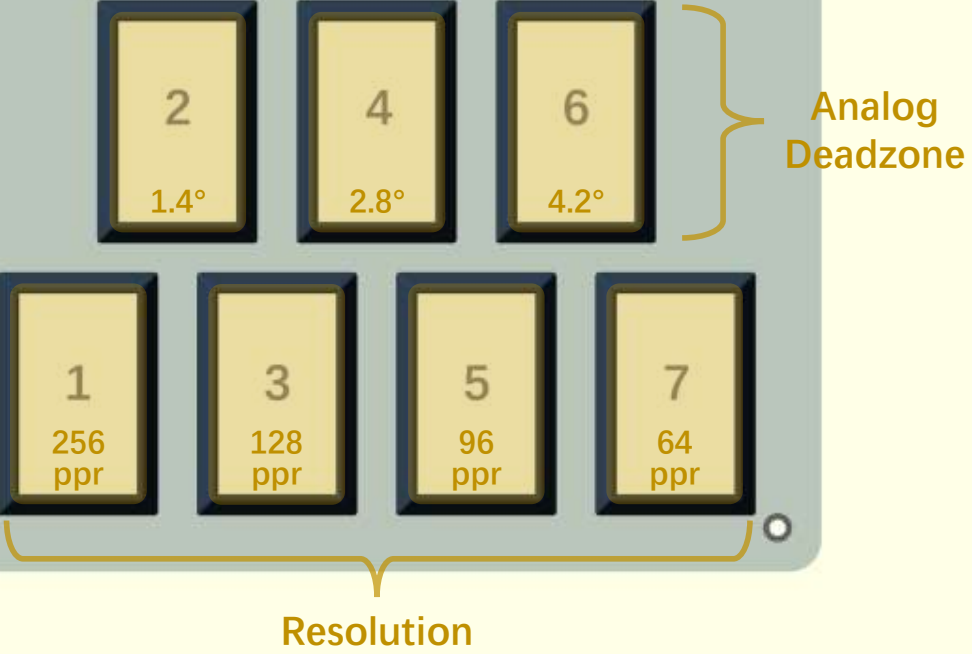
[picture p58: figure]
Analog Deadzone; Resolution; 256 ppr; 128 ppr; 96 ppr; 64 ppr

# SETUP MODE

LED Select

Normal Reversed Off

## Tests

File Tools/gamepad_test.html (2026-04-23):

# 🎮 whowechina (https://github.com/whowechina) Series Controller Testwhowechina (https://github.com/whowechina) 系列手台测试

Please connect a gamepad and press any button to activate请连接游戏手柄并按任意按钮激活

💡 HID Light ControlHID 灯光控制

Click button to connect HID device点击按钮连接 HID 设备

🔌 Connect HID Device连接 HID 设备

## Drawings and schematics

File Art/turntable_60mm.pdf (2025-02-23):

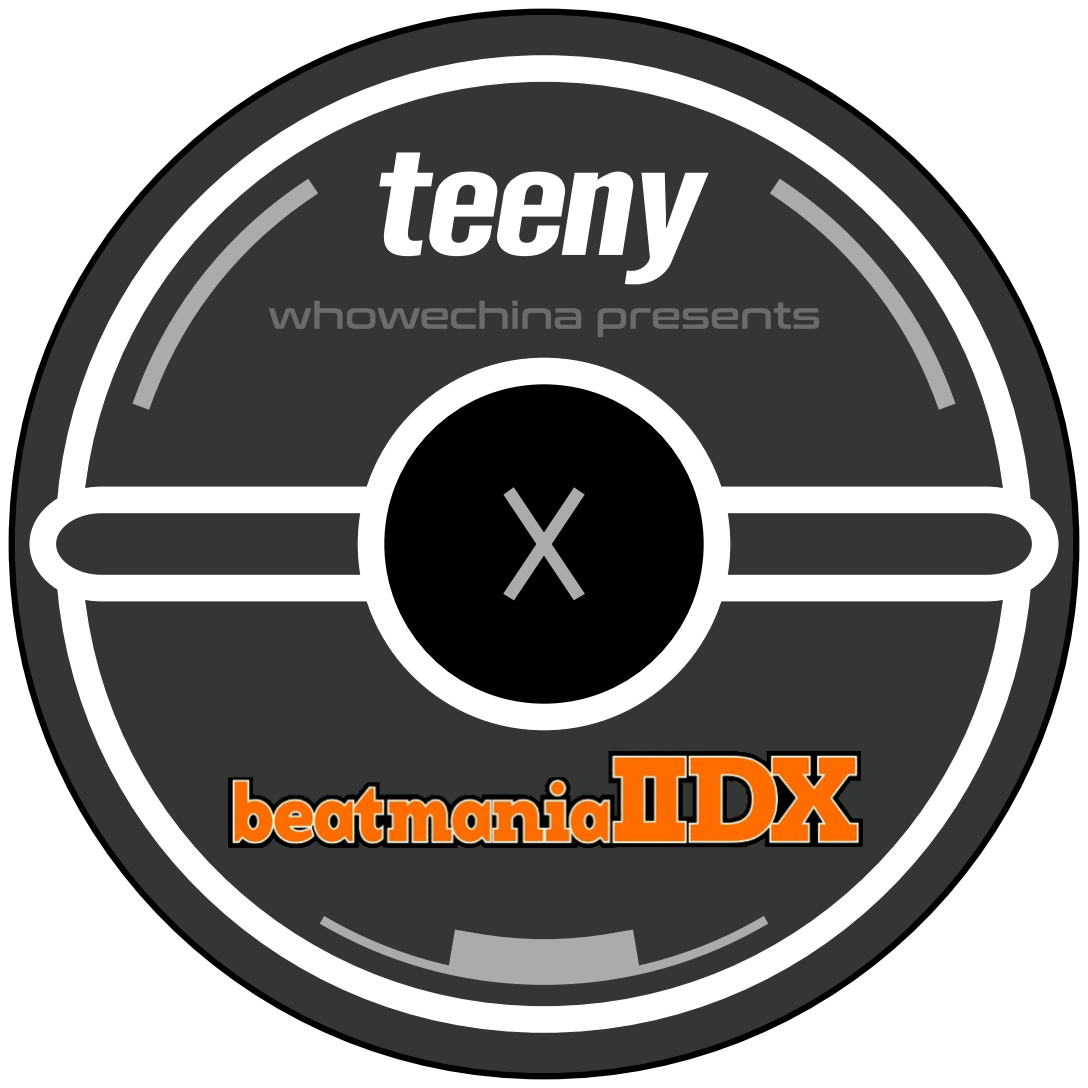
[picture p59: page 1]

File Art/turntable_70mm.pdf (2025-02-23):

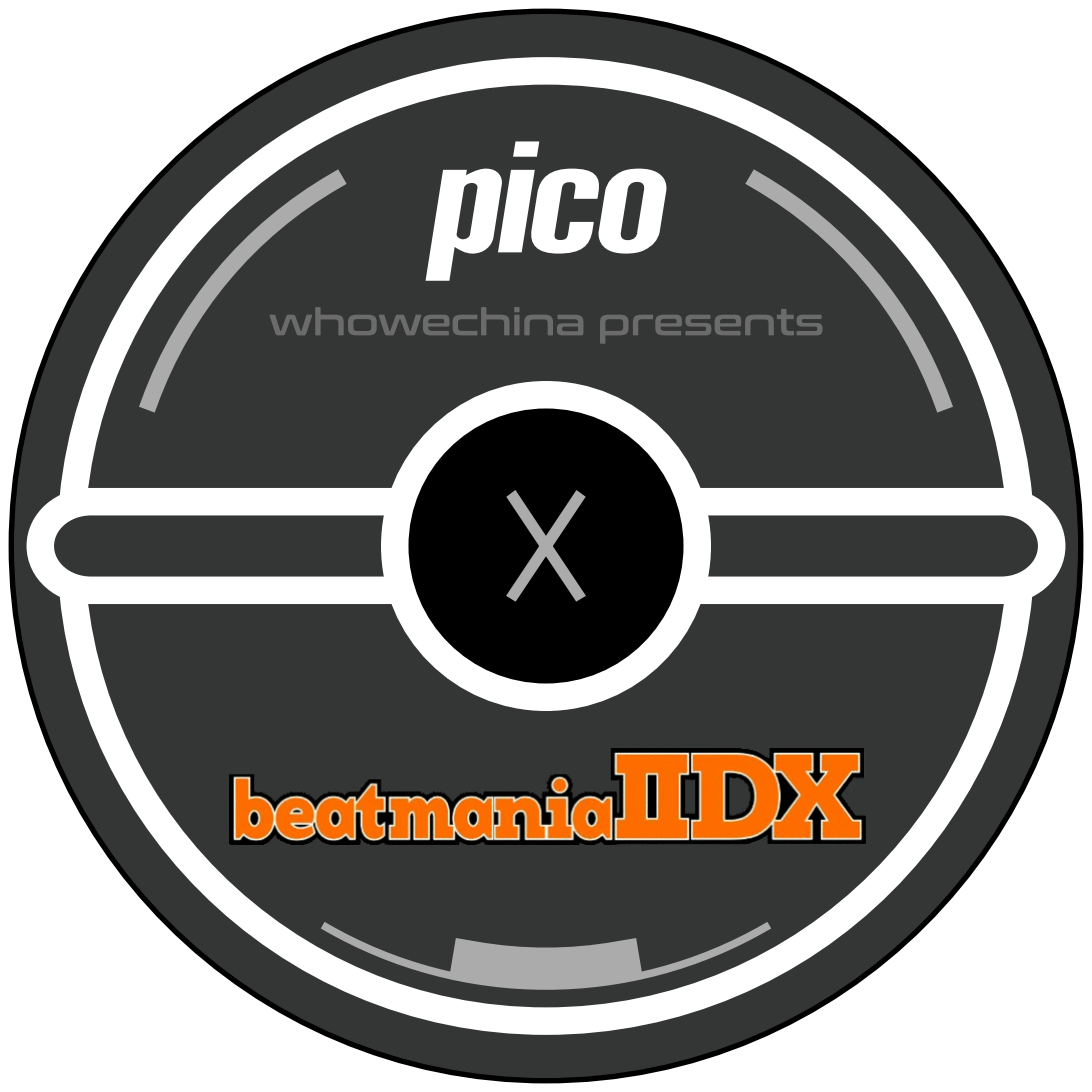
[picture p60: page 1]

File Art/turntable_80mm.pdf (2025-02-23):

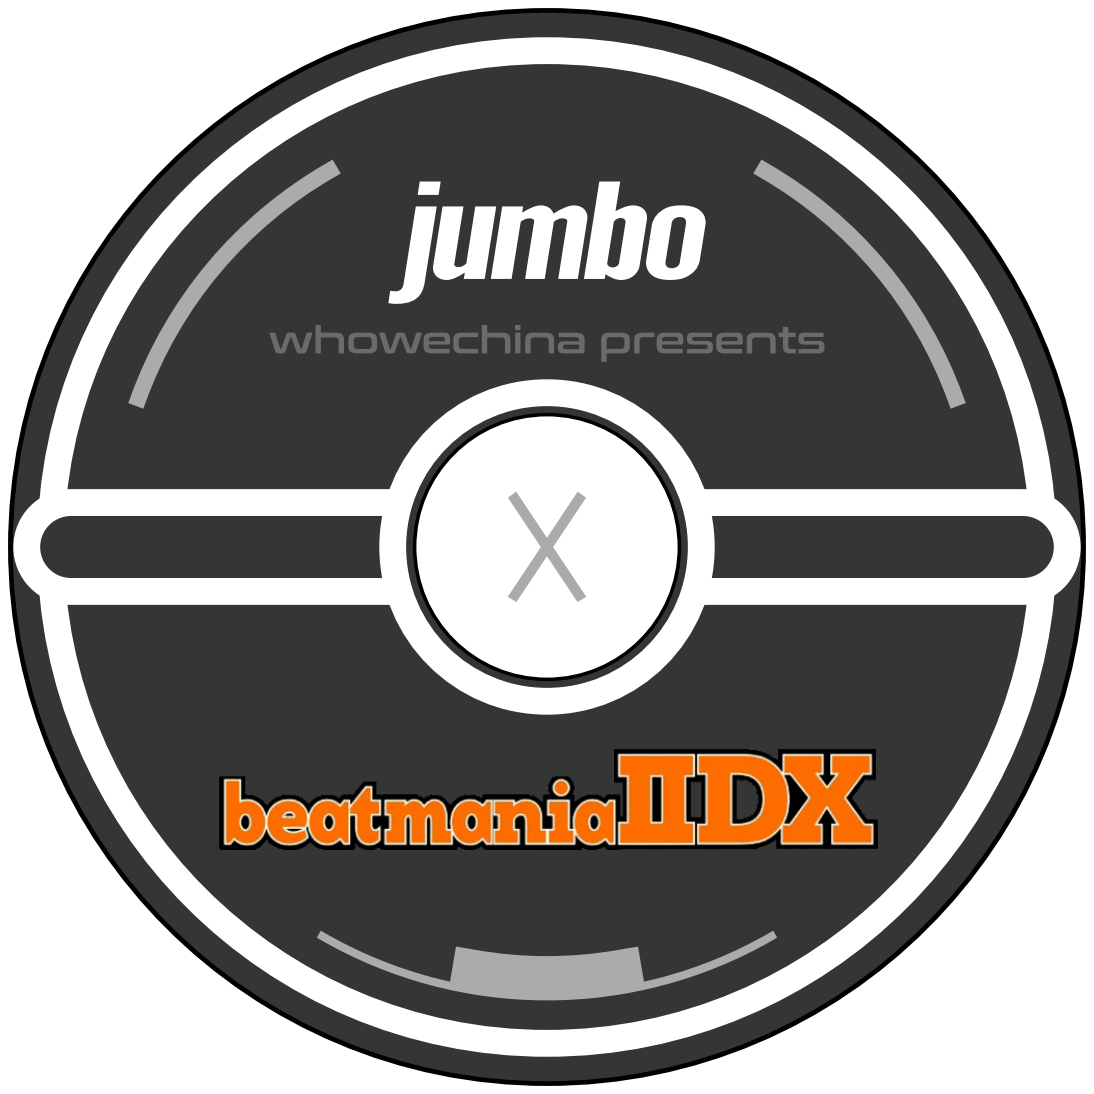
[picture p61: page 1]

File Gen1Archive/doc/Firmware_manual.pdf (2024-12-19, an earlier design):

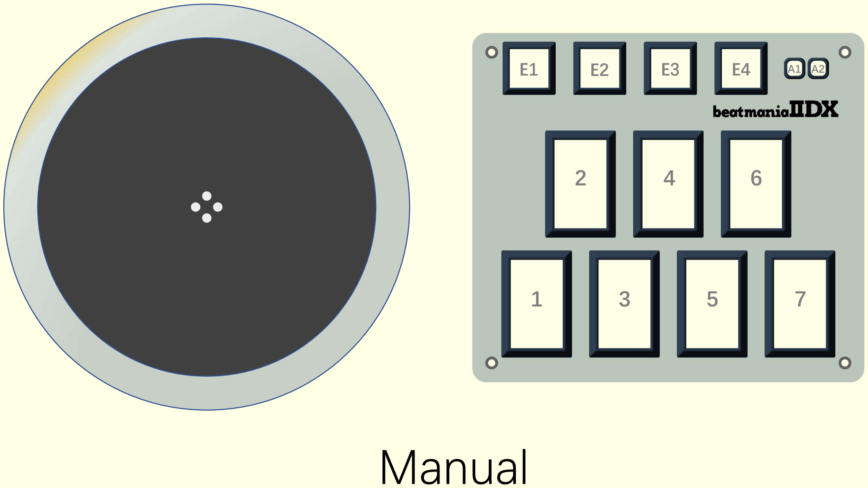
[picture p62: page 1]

1 | 3 | 5 | 7
2 | 4 | 6
E1 | E2 | E3 | E4 | A1 A2

# Manual

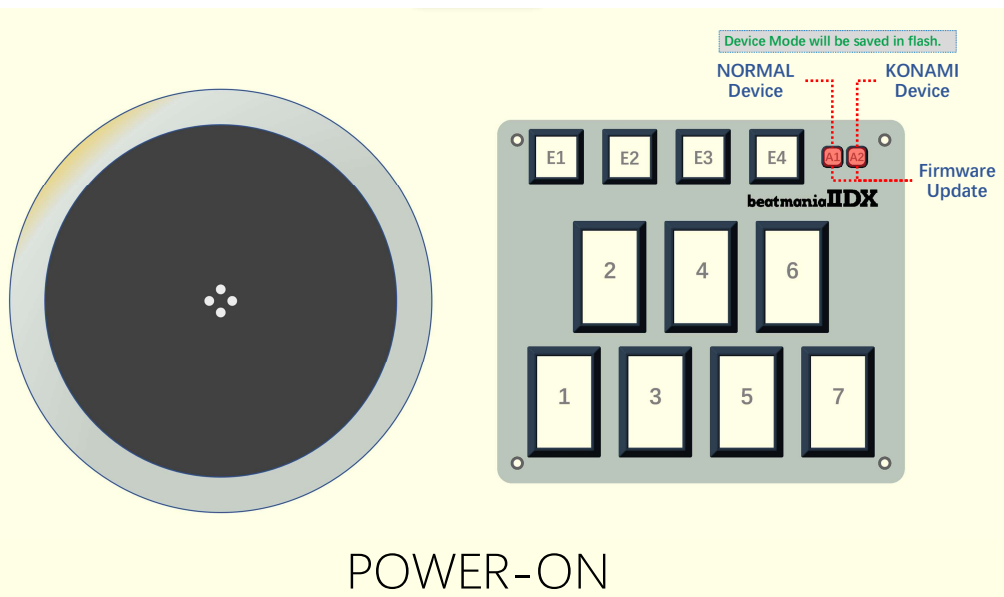
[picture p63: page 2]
POWER-ON; Firmware Update; KONAMI Device

Device Mode will be saved in flash.
NORMAL
Device

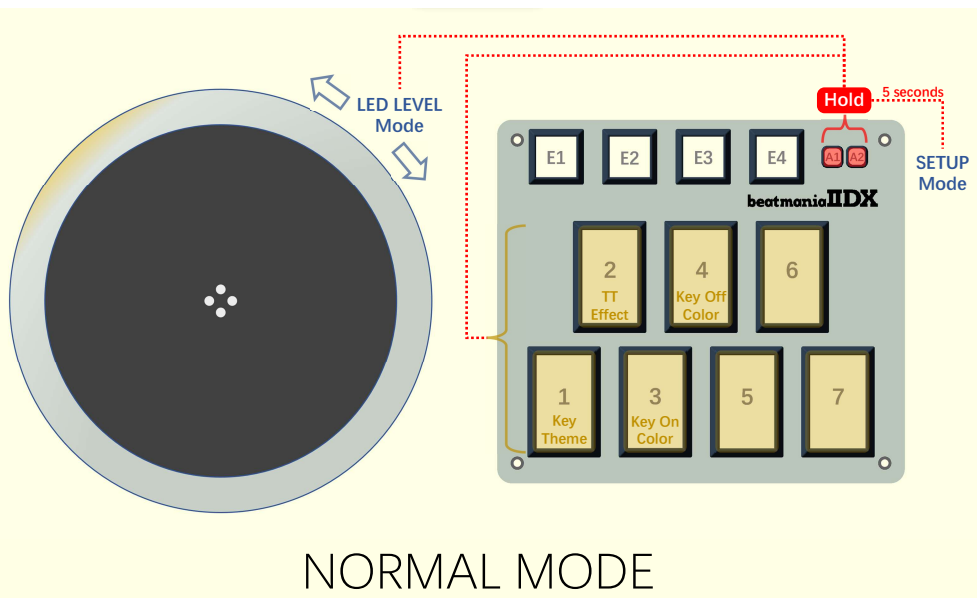
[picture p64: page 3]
NORMAL MODE; Hold; SETUP Mode; 5 seconds; TT Effect; Key Off Color; Key Theme; Key On Color; LED LEVEL Mode

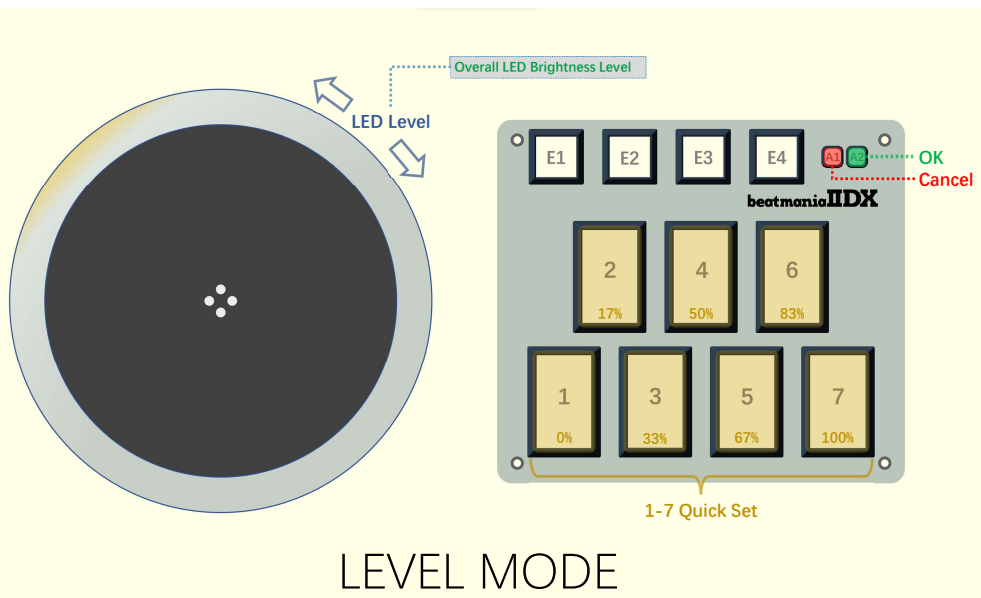
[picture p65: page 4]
LEVEL MODE; LED Level; Cancel; 1-7 Quick Set

Overall LED Brightness Level

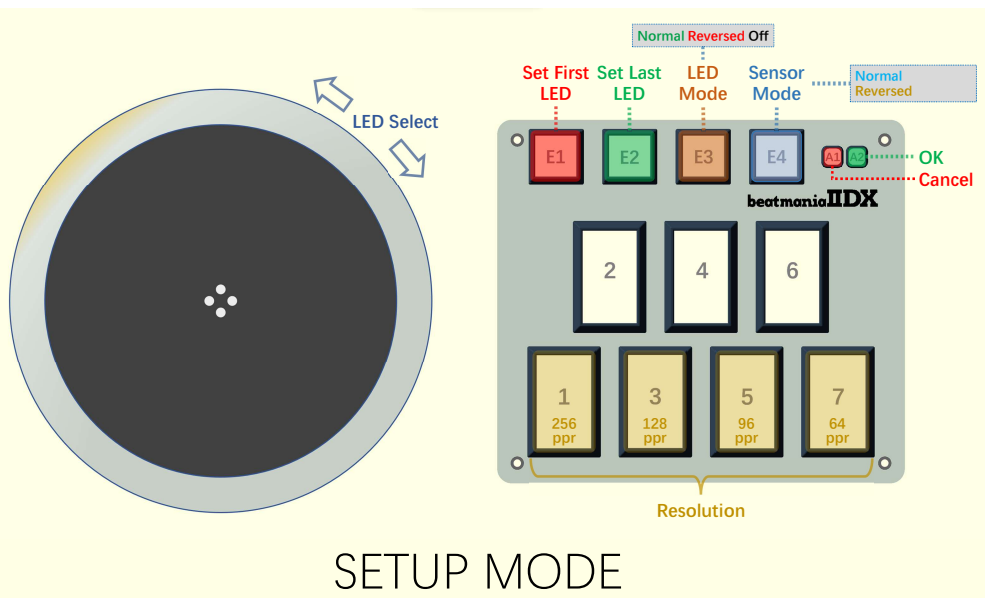
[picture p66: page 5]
SETUP MODE; LED Select; Cancel; Set First LED; LED Mode; Sensor Mode; Normal Reversed; Resolution; 256 ppr; 128 ppr; 96 ppr; 64 ppr

Normal Reversed Off
Set Last
LED

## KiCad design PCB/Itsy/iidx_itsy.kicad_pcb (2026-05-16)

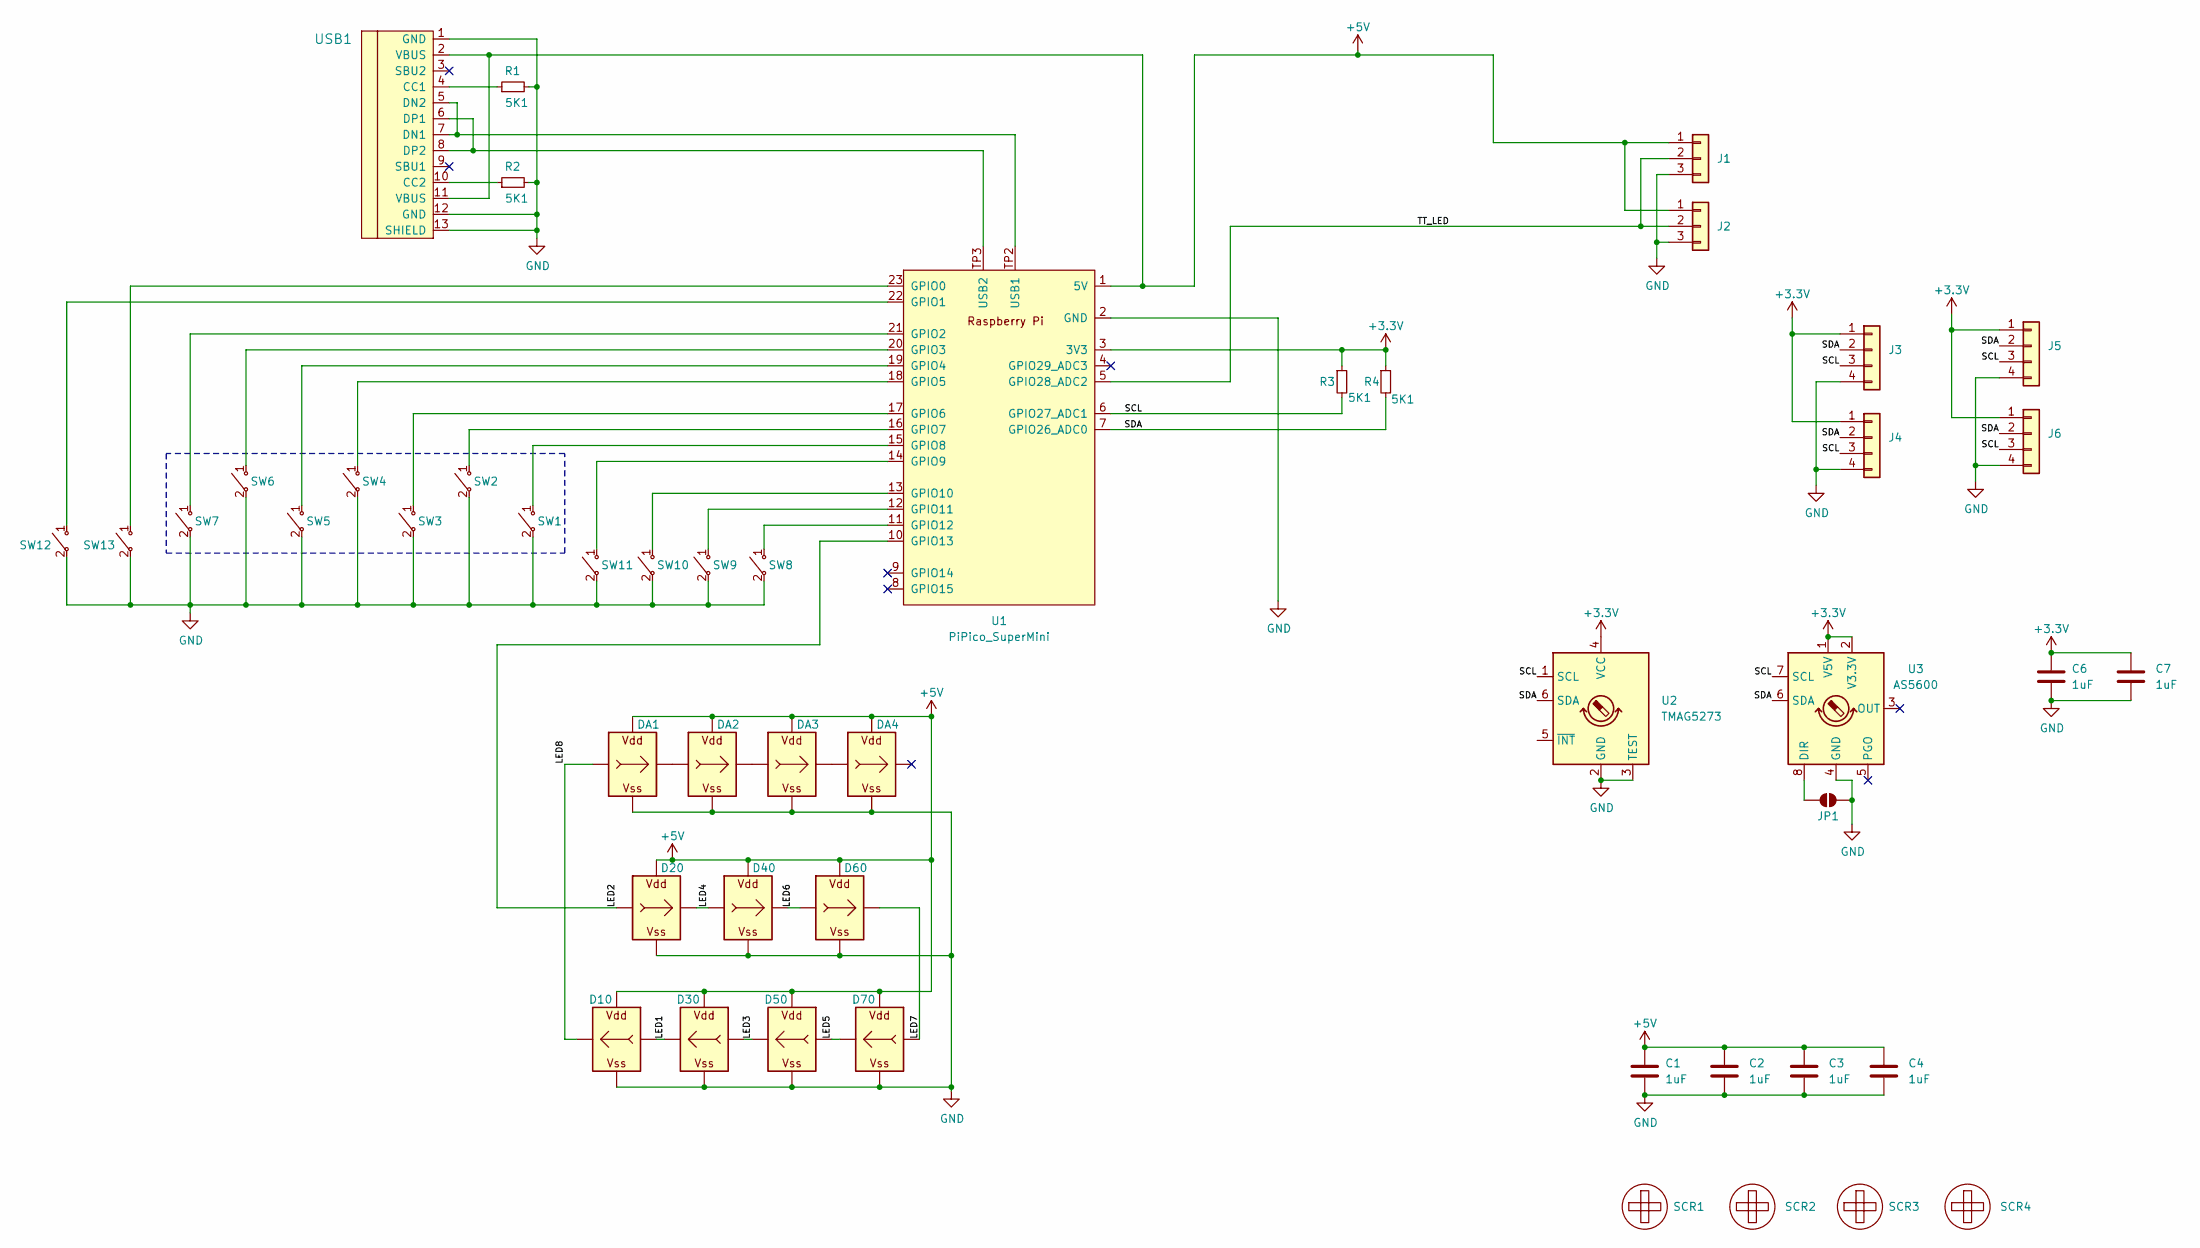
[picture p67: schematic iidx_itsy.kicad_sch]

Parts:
C1, C2, C3, C4, C6, C7: 1uF; C_0603_1608Metric_Pad1.08x0.95mm_HandSolder
D10, D20, D30, D40, D50, D60, D70: WS2812B_Unified; WS2812B-2835
DA1, DA2, DA3, DA4: WS2812B_Unified; WS2812B-2835
J1, J2: RGB; P1.8_3P_Solder
J3, J4, J5, J6: Spin; P1.8_4P_Solder
JP1: DIR; SolderJumper-2_P1.3mm_Open_RoundedPad1.0x1.5mm
R1, R2, R3, R4: 5K1; R_0603_1608Metric_Pad0.98x0.95mm_HandSolder; LCSC C23186
SCR1, SCR2, SCR3, SCR4: ScrewHole; MountingHole_3.2mm_M3
SW1, SW2, SW3, SW4, SW5, SW6, SW7: SWITCH_SPST; SW_Kailh_Choc_V1V2_1.00u_LED
SW8, SW9, SW10, SW11, SW12, SW13: SWITCH_SPST; EVQP1K05M
U1: PiPico_SuperMini; RPi_Pico_SuperMini
U2: TMAG5273; TSOT-23-6_HandSoldering
U3: AS5600; SOIC-8_3.9x4.9mm_P1.27mm
USB1: U262-161N-4BVC11; HRO-TYPE-C-31-M-12-Assembly; LCSC C319148

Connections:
+3.3V: C6.1, C7.1, J3.1, J4.1, J5.1, J6.1, R3.1, R4.1, U1.3 (3V3), U2.4 (VCC), U3.1 (V5V), U3.2 (V3.3V)
+5V: C1.1, C2.1, C3.1, C4.1, D10.V (VDD), D20.V (VDD), D30.V (VDD), D40.V (VDD), D50.V (VDD), D60.V (VDD), D70.V (VDD), DA1.V (VDD), DA2.V (VDD), DA3.V (VDD), DA4.V (VDD), J1.1, J2.1, U1.1 (5V), USB1.2 (VBUS), USB1.11 (VBUS)
/LED1: D10.I (In), D30.O (Out)
/LED2: D20.I (In), U1.10 (GPIO13)
/LED3: D30.I (In), D50.O (Out)
/LED4: D20.O (Out), D40.I (In)
/LED5: D50.I (In), D70.O (Out)
/LED6: D40.O (Out), D60.I (In)
/LED7: D60.O (Out), D70.I (In)
/LED8: D10.O (Out), DA1.I (In)
/SCL: J3.3, J4.3, J5.3, J6.3, R3.2, U1.6 (GPIO27_ADC1), U2.1 (SCL), U3.7 (SCL)
/SDA: J3.2, J4.2, J5.2, J6.2, R4.2, U1.7 (GPIO26_ADC0), U2.6 (SDA), U3.6 (SDA)
/TT_LED: J1.2, J2.2, U1.5 (GPIO28_ADC2)
GND: C1.2, C2.2, C3.2, C4.2, C6.2, C7.2, D10.G (VSS), D20.G (VSS), D30.G (VSS), D40.G (VSS), D50.G (VSS), D60.G (VSS), D70.G (VSS), DA1.G (VSS), DA2.G (VSS), DA3.G (VSS), DA4.G (VSS), J1.3, J2.3, J3.4, J4.4, J5.4, J6.4, JP1.2 (B), R1.2, R2.2, SW1.2 ("~"), SW2.2 ("~"), SW3.2 ("~"), SW4.2 ("~"), SW5.2 ("~"), SW6.2 ("~"), SW7.2 ("~"), SW8.2 ("~"), SW9.2 ("~"), SW10.2 ("~"), SW11.2 ("~"), SW12.2 ("~"), SW13.2 ("~"), U1.2 (GND), U2.2 (GND), U2.3 (TEST), U3.4 (GND), USB1.1 (GND), USB1.12 (GND), USB1.13 (SHIELD)
unnamed: DA1.O (Out), DA2.I (In)
unnamed: DA2.O (Out), DA3.I (In)
unnamed: DA3.O (Out), DA4.I (In)
unnamed: JP1.1 (A), U3.8 (DIR)
unnamed: SW13.1 ("~"), U1.23 (GPIO0)
unnamed: SW12.1 ("~"), U1.22 (GPIO1)
unnamed: SW7.1 ("~"), U1.21 (GPIO2)
unnamed: SW6.1 ("~"), U1.20 (GPIO3)
unnamed: SW5.1 ("~"), U1.19 (GPIO4)
unnamed: SW4.1 ("~"), U1.18 (GPIO5)
unnamed: SW3.1 ("~"), U1.17 (GPIO6)
unnamed: SW2.1 ("~"), U1.16 (GPIO7)
unnamed: SW1.1 ("~"), U1.15 (GPIO8)
unnamed: SW11.1 ("~"), U1.14 (GPIO9)
unnamed: SW10.1 ("~"), U1.13 (GPIO10)
unnamed: SW9.1 ("~"), U1.12 (GPIO11)
unnamed: SW8.1 ("~"), U1.11 (GPIO12)
unnamed: U1.TP2 (USB1), USB1.5 (DN2), USB1.7 (DN1)
unnamed: U1.TP3 (USB2), USB1.6 (DP1), USB1.8 (DP2)
unnamed: R1.1, USB1.4 (CC1)
unnamed: R2.1, USB1.10 (CC2)

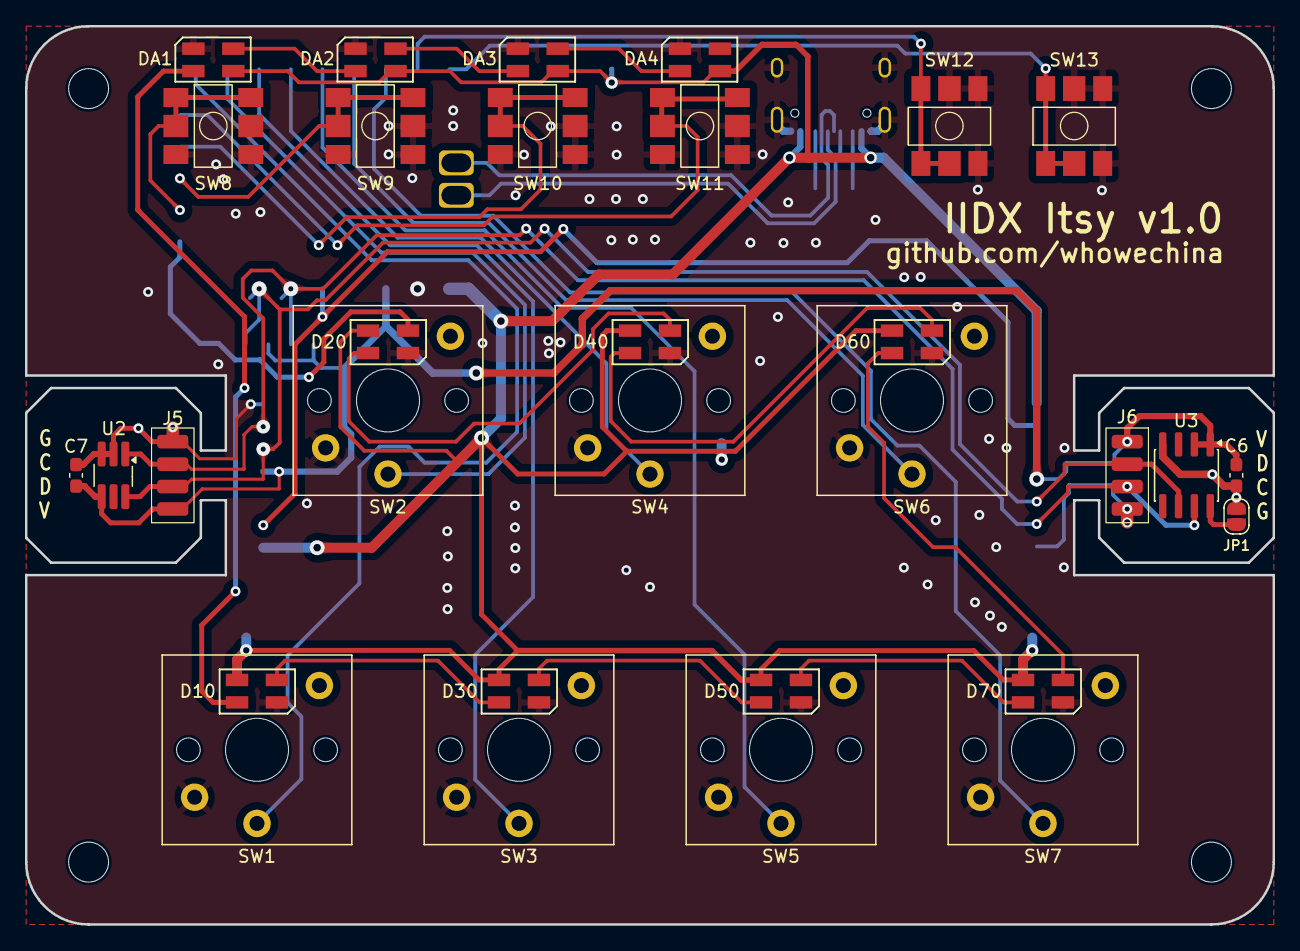
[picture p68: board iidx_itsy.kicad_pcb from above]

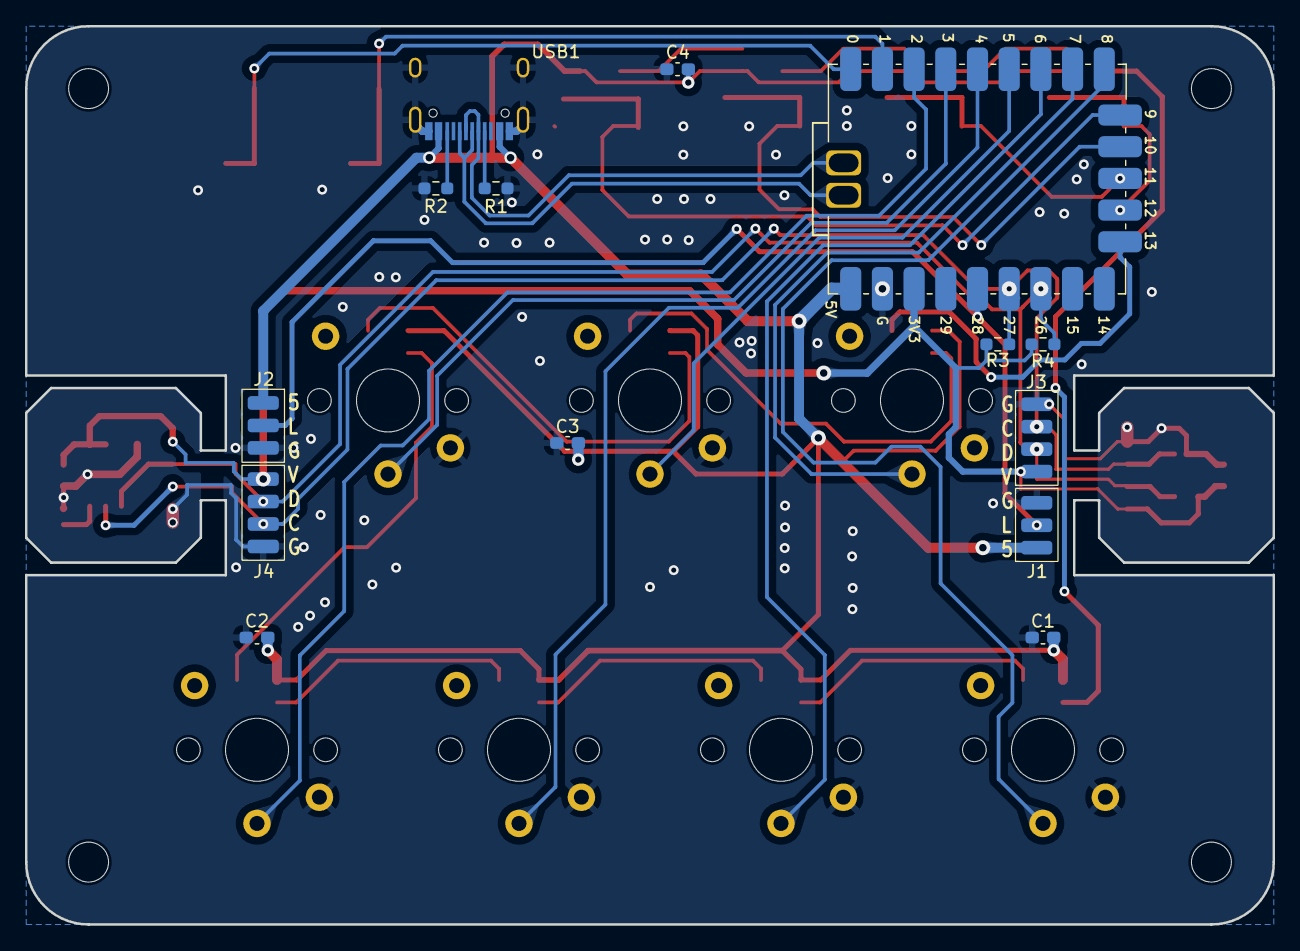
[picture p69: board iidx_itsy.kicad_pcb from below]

Board: 2 copper layers, 100.0 x 72.0 mm, 49 parts (14 on the bottom side), 35 nets.

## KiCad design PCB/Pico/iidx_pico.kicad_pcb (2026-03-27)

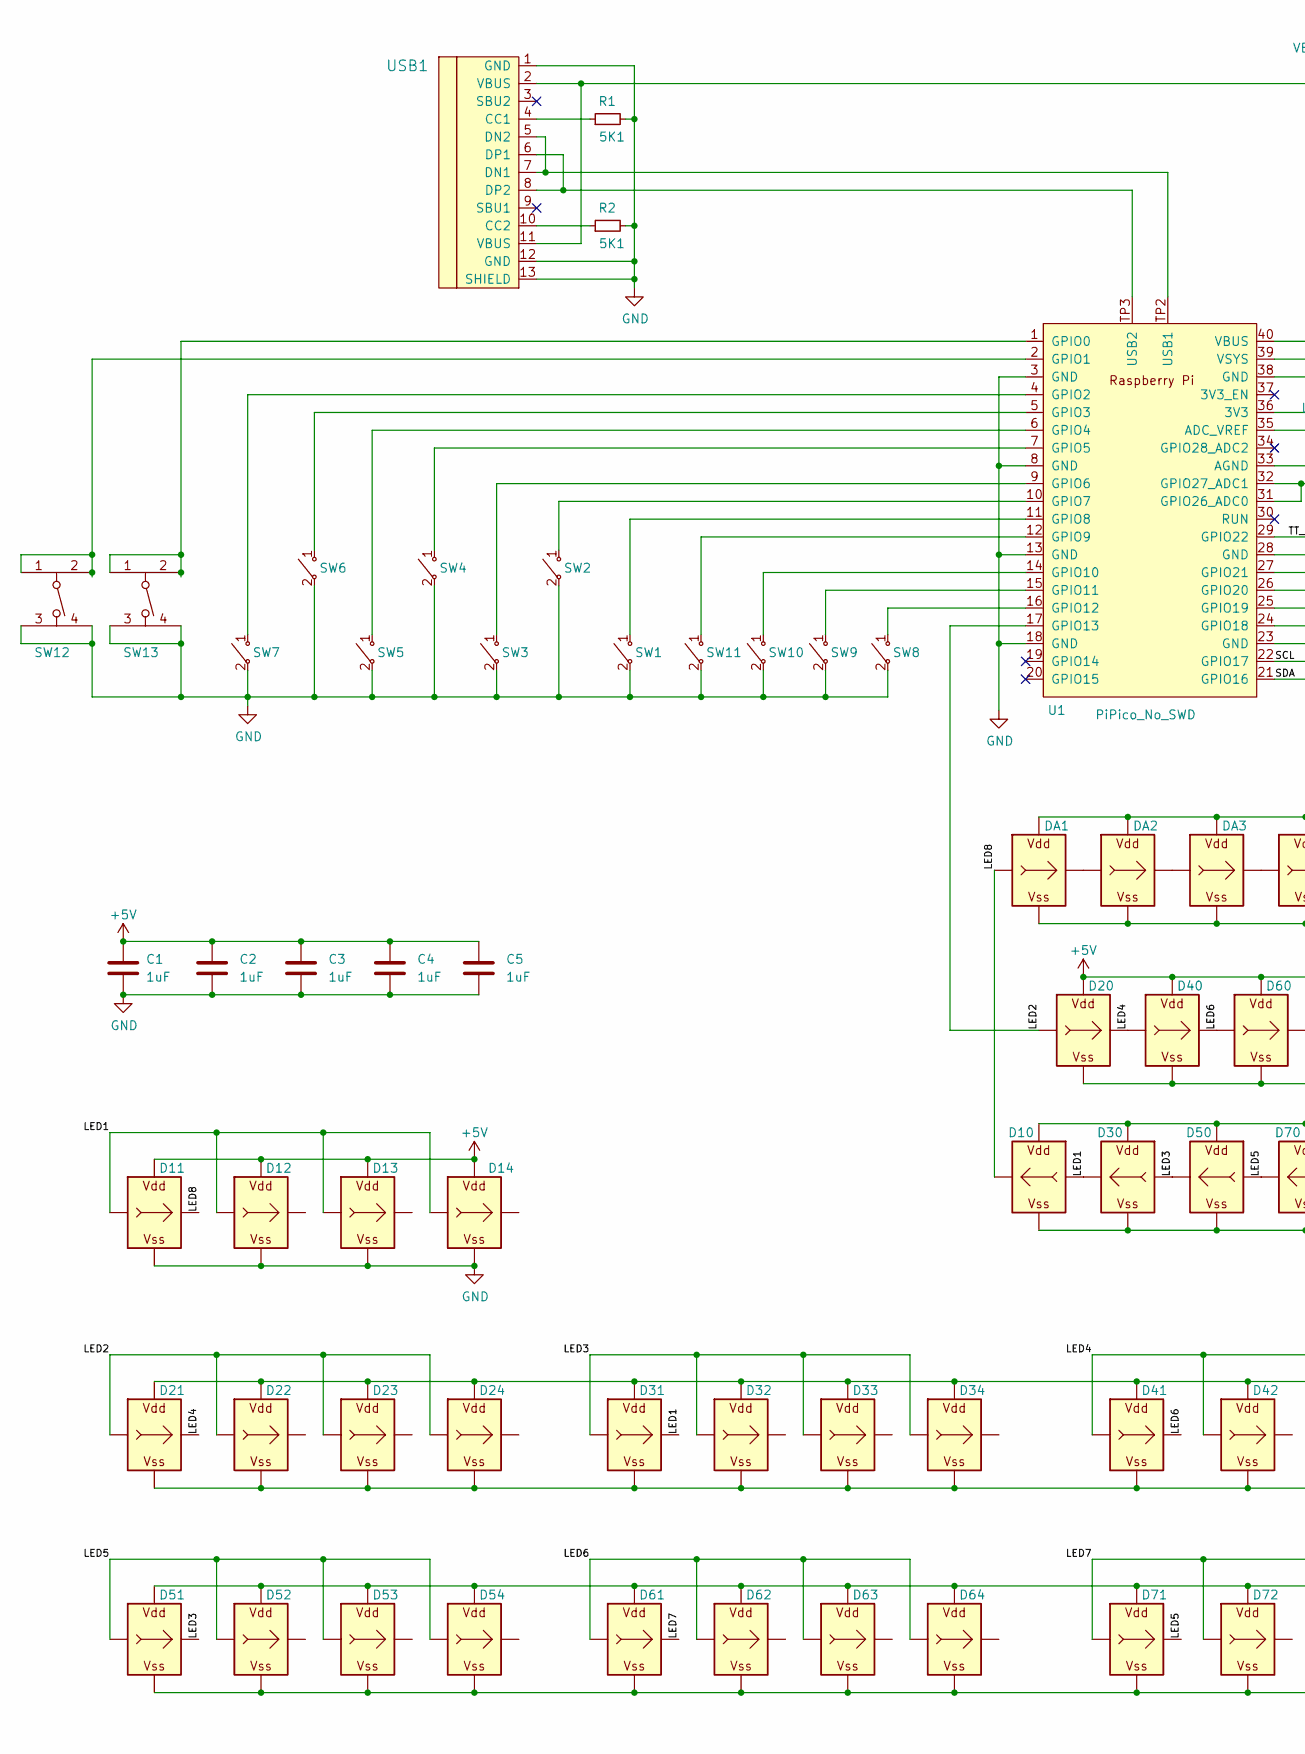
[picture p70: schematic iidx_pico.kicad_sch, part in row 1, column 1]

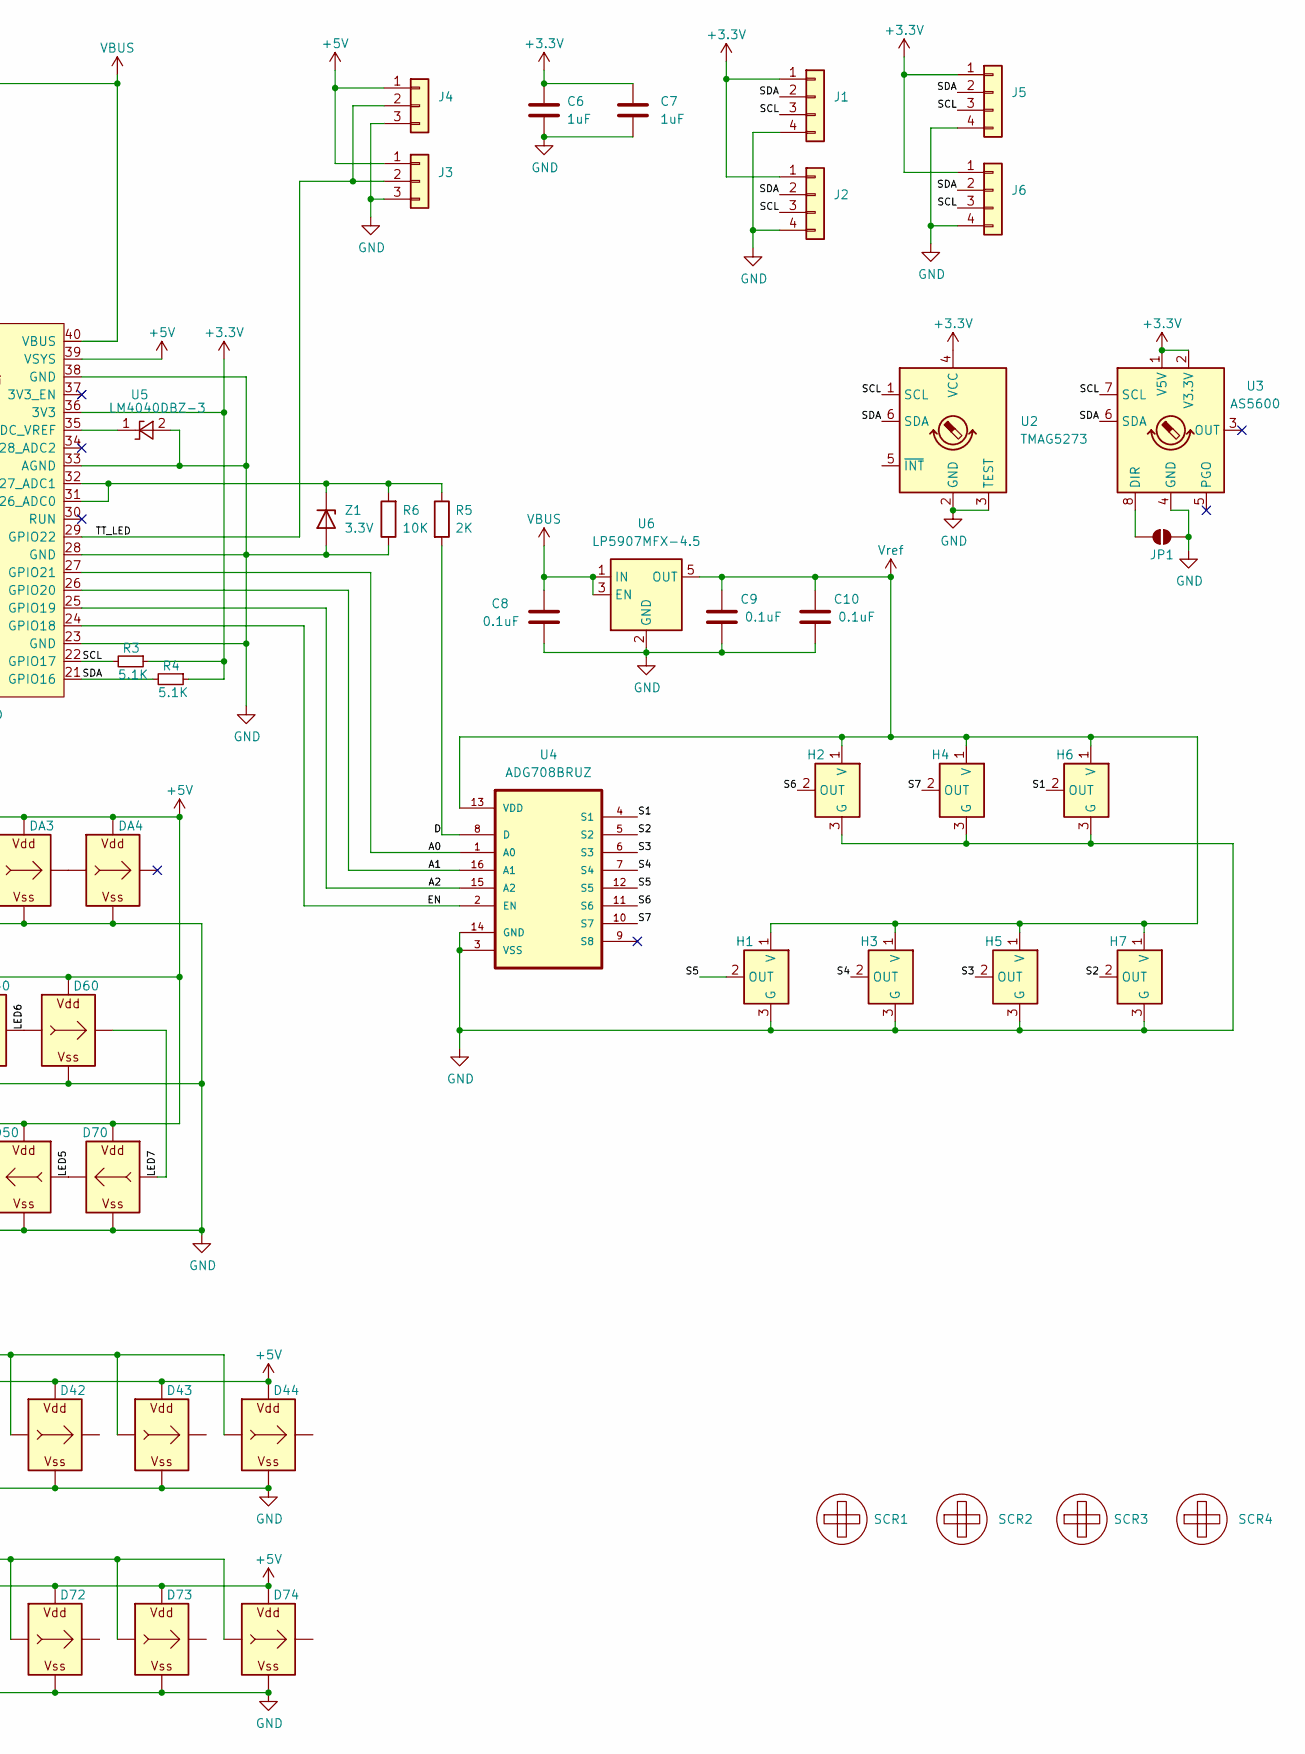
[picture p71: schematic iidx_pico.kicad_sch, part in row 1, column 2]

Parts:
C1, C2, C3, C4, C5, C6, C7: 1uF; C_0603_1608Metric_Pad1.08x0.95mm_HandSolder
C8, C9, C10: 0.1uF; C_0603_1608Metric_Pad1.08x0.95mm_HandSolder
D10, D20, D30, D40, D50, D60, D70: WS2812B_Unified; WS2812B-2835
D11, D12, D13, D14, D21, D22, D23, D24, D31, D32, D33, D34, D41, D42, D43, D44, D51, D52, D53, D54, D61, D62, D63, D64, D71, D72, D73, D74: WS2812B_Unified; WS2812B-1615
DA1, DA2, DA3, DA4: WS2812B_Unified; WS2812B-2835
H1, H2, H3, H4, H5, H6, H7: SS49E_SOT23; SOT-23-FAT
J1, J2: Spin; SH1.0_4P_Solder_Combo
J3, J4: RGB; SH1.0_3P_Solder_Combo
J5, J6: Spin; P2.0_4P_Solder
JP1: DIR; SolderJumper-2_P1.3mm_Open_RoundedPad1.0x1.5mm
R1, R2: 5K1; R_0603_1608Metric_Pad0.98x0.95mm_HandSolder; LCSC C23186
R3, R4: 5.1K; R_0603_1608Metric_Pad0.98x0.95mm_HandSolder; LCSC C23186
R5: 2K; R_0603_1608Metric_Pad0.98x0.95mm_HandSolder
R6: 10K; R_0603_1608Metric_Pad0.98x0.95mm_HandSolder
SCR1, SCR2, SCR3, SCR4: ScrewHole; MountingHole_3.2mm_M3
SW1, SW2, SW3, SW4, SW5, SW6, SW7: SWITCH_SPST; SW_Kailh_Choc_HE_IIDX
SW8, SW9, SW10, SW11: SWITCH_SPST; SW_Kailh_Choc_V1V2_1.00u_LED
SW12, SW13: Tact_4pin; EVQP1K05M; LCSC C231726
U1: PiPico_No_SWD; RPi_Pico_SMD_Pins_No_SWD
U2: TMAG5273; TSOT-23-6_HandSoldering
U3: AS5600; SOIC-8_3.9x4.9mm_P1.27mm
U4: ADG708BRUZ; TSSOP-16_4.4x5mm_P0.65mm
U5: LM4040DBZ-3; SOT-23-FAT
U6: LP5907MFX-4.5; SOT-23-5
USB1: U262-161N-4BVC11; HRO-TYPE-C-31-M-12-Assembly; LCSC C319148
Z1: 3.3V; D_SOD-123F

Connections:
+3.3V: C6.1, C7.1, J1.1, J2.1, J5.1, J6.1, R3.1, R4.1, U1.36 (3V3), U2.4 (VCC), U3.1 (V5V), U3.2 (V3.3V)
+5V: C1.1, C2.1, C3.1, C4.1, C5.1, D10.V (VDD), D11.V (VDD), D12.V (VDD), D13.V (VDD), D14.V (VDD), D20.V (VDD), D21.V (VDD), D22.V (VDD), D23.V (VDD), D24.V (VDD), D30.V (VDD), D31.V (VDD), D32.V (VDD), D33.V (VDD), D34.V (VDD), D40.V (VDD), D41.V (VDD), D42.V (VDD), D43.V (VDD), D44.V (VDD), D50.V (VDD), D51.V (VDD), D52.V (VDD), D53.V (VDD), D54.V (VDD), D60.V (VDD), D61.V (VDD), D62.V (VDD), D63.V (VDD), D64.V (VDD), D70.V (VDD), D71.V (VDD), D72.V (VDD), D73.V (VDD), D74.V (VDD), DA1.V (VDD), DA2.V (VDD), DA3.V (VDD), DA4.V (VDD), J3.1, J4.1, U1.39 (VSYS)
/A0: U1.27 (GPIO21), U4.1 (A0)
/A1: U1.26 (GPIO20), U4.16 (A1)
/A2: U1.25 (GPIO19), U4.15 (A2)
/D: R5.2, U4.8 (D)
/EN: U1.24 (GPIO18), U4.2 (EN)
/LED1: D10.I (In), D11.I (In), D12.I (In), D13.I (In), D14.I (In), D30.O (Out), D31.O (Out)
/LED2: D20.I (In), D21.I (In), D22.I (In), D23.I (In), D24.I (In), U1.17 (GPIO13)
/LED3: D30.I (In), D31.I (In), D32.I (In), D33.I (In), D34.I (In), D50.O (Out), D51.O (Out)
/LED4: D20.O (Out), D21.O (Out), D40.I (In), D41.I (In), D42.I (In), D43.I (In), D44.I (In)
/LED5: D50.I (In), D51.I (In), D52.I (In), D53.I (In), D54.I (In), D70.O (Out), D71.O (Out)
/LED6: D40.O (Out), D41.O (Out), D60.I (In), D61.I (In), D62.I (In), D63.I (In), D64.I (In)
/LED7: D60.O (Out), D61.O (Out), D70.I (In), D71.I (In), D72.I (In), D73.I (In), D74.I (In)
/LED8: D10.O (Out), D11.O (Out), DA1.I (In)
/S1: H6.2 (OUT), U4.4 (S1)
/S2: H7.2 (OUT), U4.5 (S2)
/S3: H5.2 (OUT), U4.6 (S3)
/S4: H3.2 (OUT), U4.7 (S4)
/S5: H1.2 (OUT), U4.12 (S5)
/S6: H2.2 (OUT), U4.11 (S6)
/S7: H4.2 (OUT), U4.10 (S7)
/SCL: J1.3, J2.3, J5.3, J6.3, R3.2, U1.22 (GPIO17), U2.1 (SCL), U3.7 (SCL)
/SDA: J1.2, J2.2, J5.2, J6.2, R4.2, U1.21 (GPIO16), U2.6 (SDA), U3.6 (SDA)
/TT_LED: J3.2, J4.2, U1.29 (GPIO22)
GND: C1.2, C2.2, C3.2, C4.2, C5.2, C6.2, C7.2, C8.2, C9.2, C10.2, D10.G (VSS), D11.G (VSS), D12.G (VSS), D13.G (VSS), D14.G (VSS), D20.G (VSS), D21.G (VSS), D22.G (VSS), D23.G (VSS), D24.G (VSS), D30.G (VSS), D31.G (VSS), D32.G (VSS), D33.G (VSS), D34.G (VSS), D40.G (VSS), D41.G (VSS), D42.G (VSS), D43.G (VSS), D44.G (VSS), D50.G (VSS), D51.G (VSS), D52.G (VSS), D53.G (VSS), D54.G (VSS), D60.G (VSS), D61.G (VSS), D62.G (VSS), D63.G (VSS), D64.G (VSS), D70.G (VSS), D71.G (VSS), D72.G (VSS), D73.G (VSS), D74.G (VSS), DA1.G (VSS), DA2.G (VSS), DA3.G (VSS), DA4.G (VSS), H1.3 (G), H2.3 (G), H3.3 (G), H4.3 (G), H5.3 (G), H6.3 (G), H7.3 (G), J1.4, J2.4, J3.3, J4.3, J5.4, J6.4, JP1.2 (B), R1.2, R2.2, R6.1, SW1.2 ("~"), SW2.2 ("~"), SW3.2 ("~"), SW4.2 ("~"), SW5.2 ("~"), SW6.2 ("~"), SW7.2 ("~"), SW8.2 ("~"), SW9.2 ("~"), SW10.2 ("~"), SW11.2 ("~"), SW12.3, SW12.4, SW13.3, SW13.4, U1.3 (GND), U1.8 (GND), U1.13 (GND), U1.18 (GND), U1.23 (GND), U1.28 (GND), U1.33 (AGND), U1.38 (GND), U2.2 (GND), U2.3 (TEST), U3.4 (GND), U4.3 (VSS), U4.14 (GND), U5.2 (A), U6.2 (GND), USB1.1 (GND), USB1.12 (GND), USB1.13 (SHIELD), Z1.2 (A)
unnamed: DA1.O (Out), DA2.I (In)
unnamed: DA2.O (Out), DA3.I (In)
unnamed: DA3.O (Out), DA4.I (In)
unnamed: JP1.1 (A), U3.8 (DIR)
unnamed: U1.35 (ADC_VREF), U5.1 (K)
unnamed: SW13.1, SW13.2, U1.1 (GPIO0)
unnamed: SW12.1, SW12.2, U1.2 (GPIO1)
unnamed: SW7.1 ("~"), U1.4 (GPIO2)
unnamed: SW6.1 ("~"), U1.5 (GPIO3)
unnamed: SW5.1 ("~"), U1.6 (GPIO4)
unnamed: SW4.1 ("~"), U1.7 (GPIO5)
unnamed: SW3.1 ("~"), U1.9 (GPIO6)
unnamed: SW2.1 ("~"), U1.10 (GPIO7)
unnamed: SW1.1 ("~"), U1.11 (GPIO8)
unnamed: SW11.1 ("~"), U1.12 (GPIO9)
unnamed: SW10.1 ("~"), U1.14 (GPIO10)
unnamed: SW9.1 ("~"), U1.15 (GPIO11)
unnamed: SW8.1 ("~"), U1.16 (GPIO12)
unnamed: R5.1, R6.2, U1.31 (GPIO26_ADC0), U1.32 (GPIO27_ADC1), Z1.1 (K)
unnamed: U1.TP2 (USB1), USB1.5 (DN2), USB1.7 (DN1)
unnamed: U1.TP3 (USB2), USB1.6 (DP1), USB1.8 (DP2)
unnamed: R1.1, USB1.4 (CC1)
unnamed: R2.1, USB1.10 (CC2)
VBUS: C8.1, U1.40 (VBUS), U6.1 (IN), U6.3 (EN), USB1.2 (VBUS), USB1.11 (VBUS)
Vref: C9.1, C10.1, H1.1 (V), H2.1 (V), H3.1 (V), H4.1 (V), H5.1 (V), H6.1 (V), H7.1 (V), U4.13 (VDD), U6.5 (OUT)

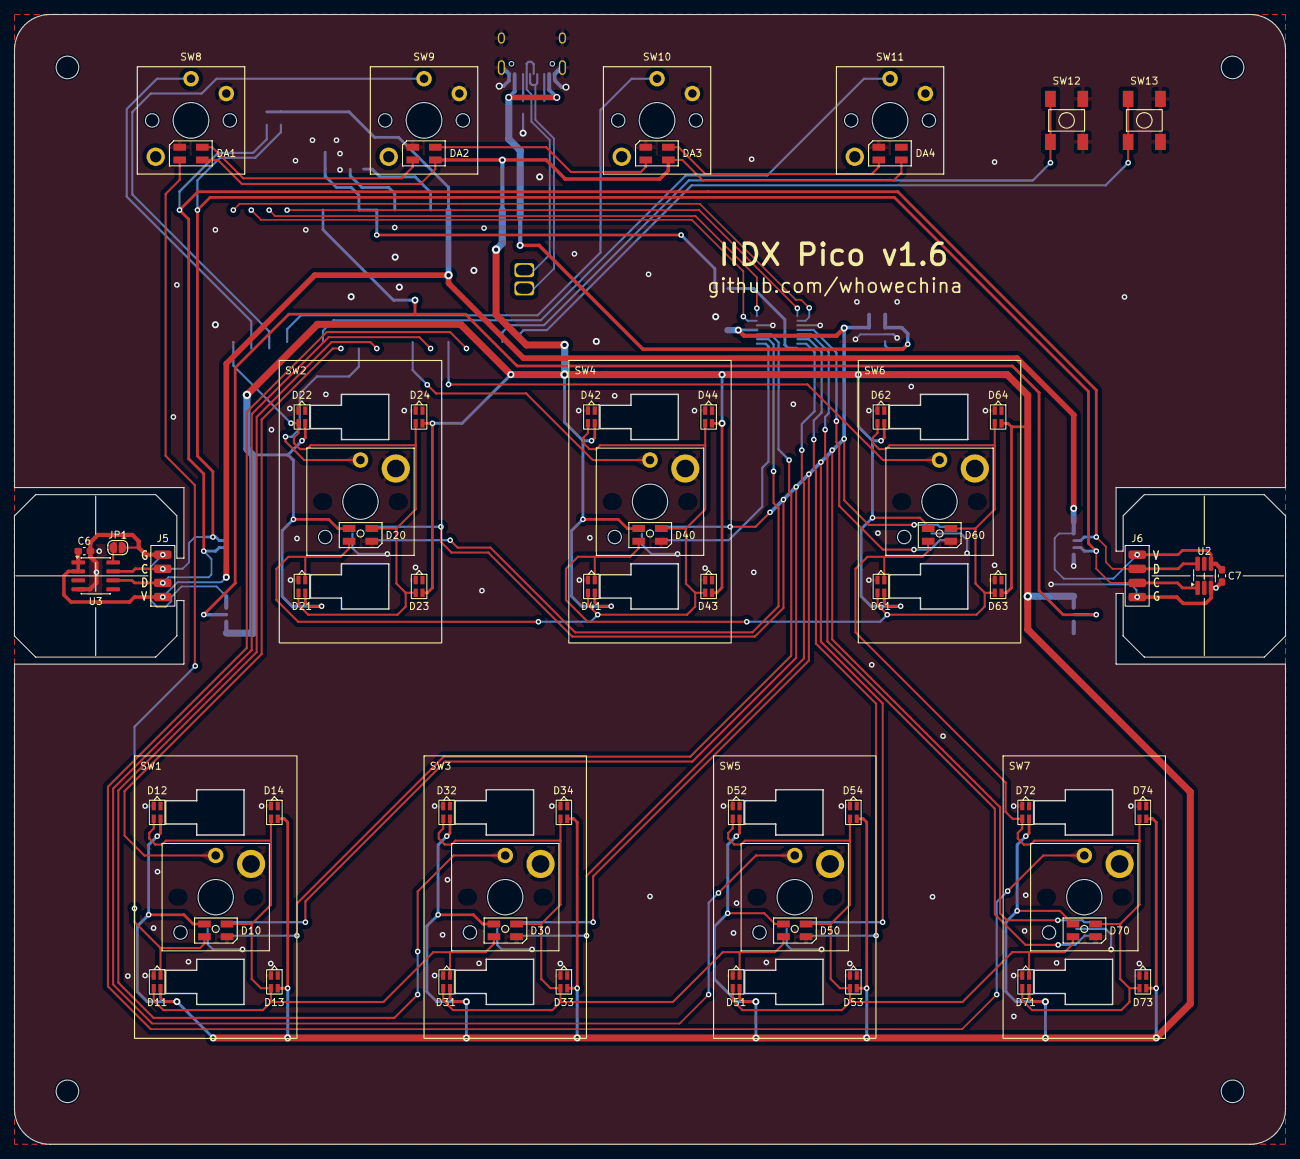
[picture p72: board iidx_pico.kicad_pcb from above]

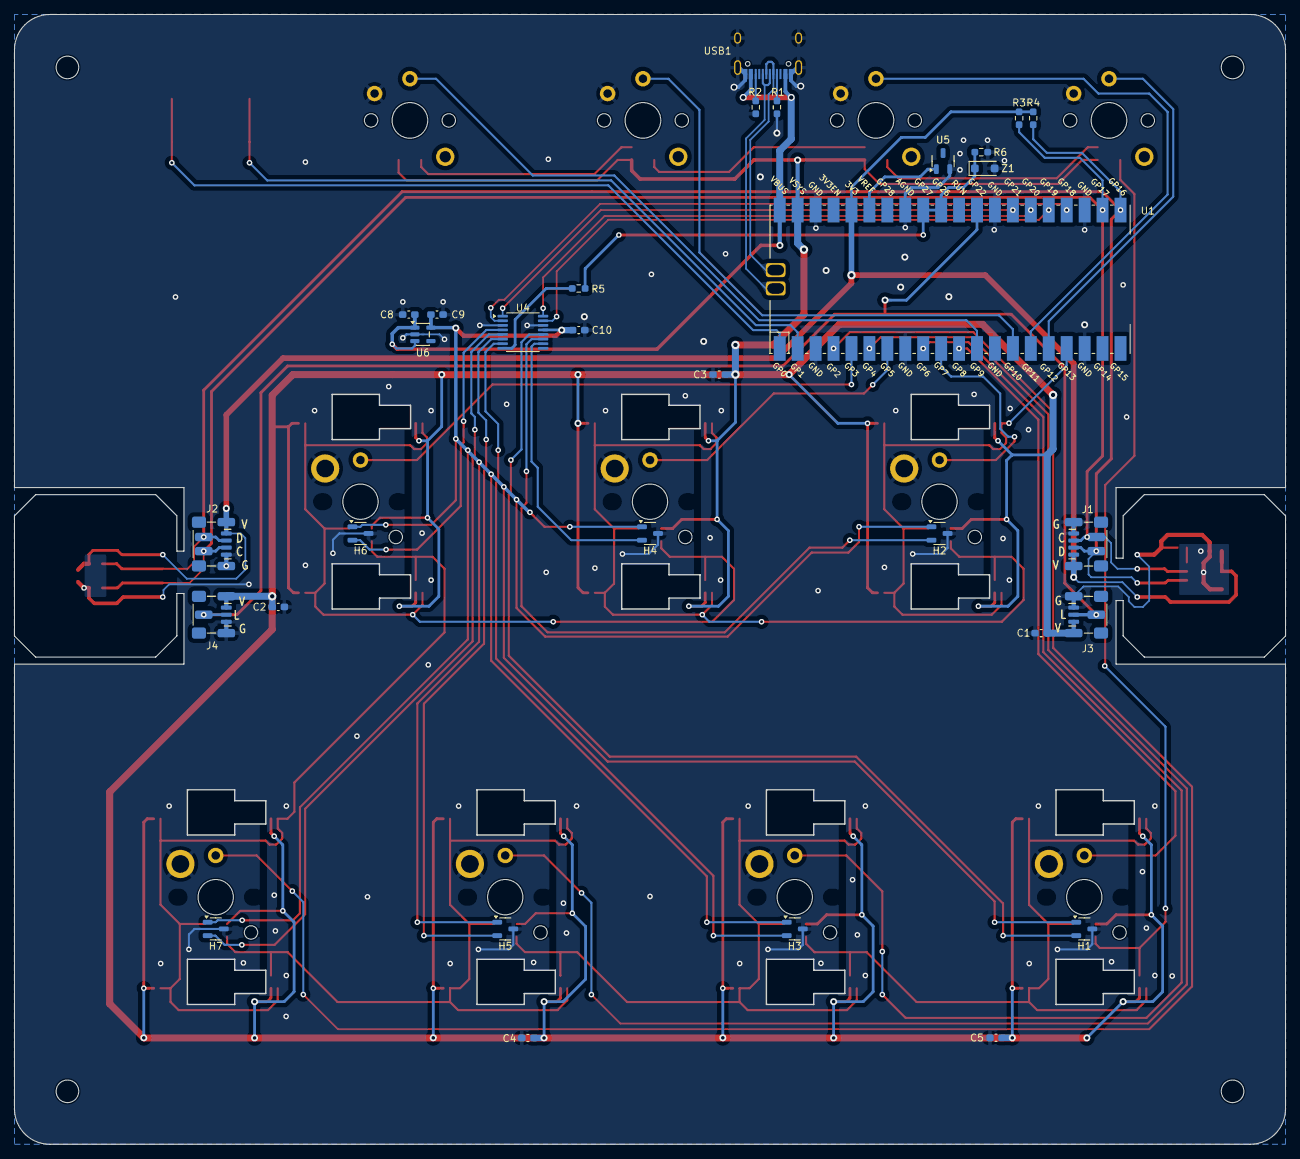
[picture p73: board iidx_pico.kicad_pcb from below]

Board: 2 copper layers, 180.0 x 160.0 mm, 94 parts (31 on the bottom side), 51 nets.

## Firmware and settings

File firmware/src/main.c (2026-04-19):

/*
 * Controller Main
 * WHowe <github.com/whowechina>
 */

#include <stdint.h>
#include <stdbool.h>

#include "bsp/board.h"
#include "pico/multicore.h"
#include "pico/bootrom.h"
#include "pico/stdio.h"
#include "hardware/watchdog.h"

#include "tusb.h"
#include "usb_descriptors.h"

#include "setup.h"

#include "buttons.h"
#include "hebtn.h"
#include "rgb.h"
#include "turntable.h"

#include "tt_blade.h"
#include "tt_rainbow.h"
#include "tt_heatbar.h"

#include "savedata.h"
#include "config.h"
#include "cli.h"
#include "commands.h"

struct __attribute__((packed)) {
    uint16_t buttons;
    uint8_t axis[2];
} hid_joy, hid_joy_sent;

void report_usb_hid()
{
    static uint64_t last_report_time = 0;
    if (tud_hid_ready()) {
        uint64_t now = time_us_64();
        if ((memcmp(&hid_joy, &hid_joy_sent, sizeof(hid_joy)) == 0) &&
            (now - last_report_time < 10000)) {
            return;
        }
        last_report_time = now;
        if (tud_hid_report(REPORT_ID_JOYSTICK, &hid_joy, sizeof(hid_joy))) {
            hid_joy_sent = hid_joy;
        }
    }
}

#define AUX_1_BIT 12
#define AUX_2_BIT 11

#define E1_BIT 7
#define E2_BIT 8
#define E3_BIT 9
#define E4_BIT 10

void boot_check()
{
    uint16_t key1 = (1 << AUX_1_BIT);
    uint16_t key2 = (1 << AUX_2_BIT);
    uint16_t buttons = button_read();
    if (!watchdog_caused_reboot() && (buttons & key1) && (buttons & key2)) {
        reset_usb_boot(0, 2);
    }
}
 
void mode_check()
{
    uint16_t key1 = (1 << AUX_1_BIT);
    uint16_t key2 = (1 << AUX_2_BIT);
    uint16_t buttons = button_read();
    if (buttons & key1) {
        iidx_cfg->hid.konami = true;
        savedata_save(false);
    } else if (buttons & key2) {
        iidx_cfg->hid.konami = false;
        savedata_save(false);
    }

    if (iidx_cfg->hid.konami) {
        switch_to_konami_mode();
    }
}

static void factory_check()
{
    uint16_t e_mask = (1 << E1_BIT) | (1 << E2_BIT) | (1 << E3_BIT) | (1 << E4_BIT);
    if ((button_read() & e_mask) == e_mask) {
        config_factory_reset();
    }
}

static uint16_t latest_hybrid_buttons;

static void hybrid_button_update()
{
    uint16_t buttons = button_read();
    for (int i = 0; i < hebtn_keynum(); i++) {
        if (hebtn_present(i)) {
            buttons |= (hebtn_actuated(i) << i);
        }
    }
    latest_hybrid_buttons = buttons;
}

static uint16_t hybrid_button_read()
{
    return latest_hybrid_buttons;
}

#define TT_HOLD_TIME_MS 200

static void gen_binary_tt(uint8_t angle)
{
    static uint8_t previous_angle = 0;
    static bool tt_active = false;
    static bool tt_dir_cw = false;
    static uint32_t tt_timeout = 0;

    int8_t delta = angle - previous_angle;
    previous_angle = angle;

    uint64_t now = time_us_32();

    if (delta != 0) {
        tt_active = true;
        tt_dir_cw = (delta > 0);
        tt_timeout = now + TT_HOLD_TIME_MS * 1000;
    } else if (tt_active && (now > tt_timeout)) {
        tt_active = false;
    }

    hid_joy.axis[0] = tt_active ? (tt_dir_cw ? 0xff : 0x00) : 0x80;
    hid_joy.axis[1] = 0x80;
}

static void gen_hid_report()
{
    uint16_t buttons = hybrid_button_read();
    uint8_t angle = turntable_read(8);

    if (iidx_cfg->hid.konami) {
        uint16_t aux_buttons = buttons & 0xff80;
        buttons = (buttons & 0x7f) | (aux_buttons << 1); // skips button 8
    }
    hid_joy.buttons = buttons;

    if (iidx_cfg->sensor.binary) {
        gen_binary_tt(angle);
    } else {
        hid_joy.axis[0] = angle;
        hid_joy.axis[1] = 255 - hid_joy.axis[0];
    }
}

static void core1_init()
{
    flash_safe_execute_core_init();
}

static void core1_loop()
{
    core1_init();

    while (true) {
        rgb_update(turntable_read_abs(12), hybrid_button_read());
        cli_fps_count(1);
        sleep_us(500);
    }
}

static bool is_hall_board = false;

static void core0_loop()
{
    absolute_time_t next_frame = {0};

    while (true)
    {
        tud_task();
        cli_run();

        if (is_hall_board) {
            hebtn_update();
        }

        turntable_update();
        hybrid_button_update();

        uint16_t buttons = hybrid_button_read();
        uint16_t abs_angle = turntable_read_abs(8);
        setup_run(buttons, abs_angle);

        bool ov_tt = setup_needs_tt_led();
        bool ov_btn = setup_needs_button_led();

        if (ov_tt) {
            rgb_override_tt(setup_led_tt);
        }
        if (ov_btn) {
            rgb_override_button(setup_led_button);
        } else {
            rgb_set_button_light(buttons);
        }

        hid_joy.buttons = 0;
        if (!ov_tt && !ov_btn) {
            gen_hid_report();
            savedata_loop();
        }

        report_usb_hid();
        cli_fps_count(0);

        sleep_until(next_frame);
        next_frame += 1000;
    }
}

void init()
{
    board_init();
    tusb_init();
    
    button_init();

    bool tt_present = turntable_init();

    if ((tt_present) && (turntable_is_alternative())) {
        // identify hall version by sensor's i2c port
        is_hall_board = true;
        hebtn_init();
    }

    if (!tt_present) {
        // even if tt not available, we still try to detect hall sensor
        hebtn_init();
        is_hall_board = (hebtn_presence_map() > 0);
    }

    rgb_init(is_hall_board);

    tt_rainbow_init();
    tt_blade_init();
    tt_heatbar_init();

    boot_check();
    stdio_init_all();

    setup_init();
    config_init();
    savedata_init(0xca341125);

    factory_check();
    mode_check();

    cli_init("iidx_pico>", "\n   << IIDX Pico|Teeny Controller >>\n"
                            " https://github.com/whowechina\n\n");
    commands_init();
}

void main(void)
{
    init();
    multicore_launch_core1(core1_loop);
    core0_loop();
}

// Invoked when received GET_REPORT control request
// Application must fill buffer report's content and return its length.
// Return zero will cause the stack to STALL request
uint16_t tud_hid_get_report_cb(uint8_t itf, uint8_t report_id,
                               hid_report_type_t report_type, uint8_t *buffer,
                               uint16_t reqlen)
{
    return 0;
}

// Invoked when received SET_REPORT control request or
// received data on OUT endpoint ( Report ID = 0, Type = 0 )
void tud_hid_set_report_cb(uint8_t itf, uint8_t report_id,
                           hid_report_type_t report_type, uint8_t const *buffer,
                           uint16_t bufsize)
{
    if ((report_id == REPORT_ID_LIGHTS) &&
        (report_type == HID_REPORT_TYPE_OUTPUT)) {
        rgb_set_hid_light(buffer, bufsize);
    }
}

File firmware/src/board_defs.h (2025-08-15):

/*
 * IIDX Controller Board Definitions
 * WHowe <github.com/whowechina>
 */

#if defined BOARD_IIDX_PICO
/* List of button pins */
#define BUTTON_DEF { 8, 7, 6, 5, 4, 3, 2, 12, 11, 10, 9, 1, 0 }

#define BUTTON_RGB_PIN 13
#define BUTTON_RGB_ORDER GRB // or RGB

#define BUTTON_RGB_NUM 11
#define BUTTON_RGB_MAP { 6, 0, 5, 1, 4, 2, 3, 7, 8, 9, 10}

#define TT_RGB_PIN 28
#define TT_RGB_PIN_2 22
#define TT_RGB_ORDER GRB // or RGB

#define TT_SENSOR_SCL 27
#define TT_SENSOR_SDA 26
#define TT_SENSOR_I2C i2c1

#define TT_SENSOR_SCL_2 17
#define TT_SENSOR_SDA_2 16
#define TT_SENSOR_I2C_2 i2c0

#define TT_SENSOR_I2C_FREQ 377 * 1000

#define HALL_MUX_EN 18
#define HALL_MUX_A0 21
#define HALL_MUX_A1 20
#define HALL_MUX_A2 19

#define HALL_ADC_CHANNEL 1
#define HALL_KEY_NUM 7
#define HALL_KEY_MUX_MAP { 4, 5, 3, 6, 2, 0, 1 }

#else

#endif

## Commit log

2023-04-01 Migrate to iidx_pico public repo
    [Credit Button Assy (Groovy).step, EVQ-P1D05M.stp, J 2835.step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]
2023-04-01 Materials part in README
2023-04-01 More updates.
    [kb_assemble.scad]
2023-04-02 Better numbers on TTshaft
    [TTshaft.scad, TTshaft_6804.stl, TTshaft_6805.stl]
2023-04-02 Easier to define a magnet in TTshaft
    [TTshaft.scad, TTshaft_6804.stl, TTshaft_6805.stl]
2023-04-02 Better numbers for bearing seat
    [bearing_seat.scad, bearing_seat_6804.stl, bearing_seat_6805.stl]
2023-04-02 Created PCB for turntable
    [Credit Button Assy (Groovy).step, EVQ-P1D05M.stp, J 2835.step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]
2023-04-02 Update turntable PCB
    [TT_assemble_6804.scad, TT_base.scad, iidx_tt v1.stl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]
2023-04-02 Turntable gerber added
    [iidx_tt.kicad_pcb]
2023-04-02 Production categorization
    [TT_base.stl, TT_base_150.stl, TT_base_170.stl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]
2023-04-04 Some progress
    [TTshaft.scad, TTshaft_6804.stl, TTshaft_6805.stl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]
2023-04-06 3.3 to 5 level shifter added to PCB
    [iidx_pico.kicad_pcb, iidx_pico.kicad_sch]
2023-04-07 Adds 3.5mm 4P jack connection option
    [User Library-pj-393-8.STEP, iidx_pico.kicad_pcb, iidx_pico.kicad_sch]
2023-04-08 PCB bottom supports headphone jack
    [pcb_bottom.scad, pcb_bottom.stl, pcb_bottom_both_connectors.stl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]
2023-04-08 PCB finetune a little bit
    [iidx_pico.kicad_pcb]
2023-04-09 Dynamic LED setup working
2023-04-11 Update Readme for keyboard soldering
2023-04-11 Add TVS diode and filter capacitor to PCB
    [iidx_pico.kicad_pcb, iidx_pico.kicad_sch]
2023-04-14 I2C to 333KHz for higher reliability.
2023-04-15 Document update on solder part
2023-04-16 Analog and I2C mode change at runtime
2023-04-16 Resistors to bypass level shifter
    [iidx_pico.kicad_pcb, iidx_pico.kicad_sch]
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2023-04-22 Choc V2 FDM option optimized
    [iidx_keycap_choc_v1_sla.stl, iidx_keycap_choc_v2_fdm.stl, iidx_keycap_choc_v2_sla.stl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]
2023-04-29 Larger PCB bottom pads
    [pcb_bottom.scad, pcb_bottom_both_connectors.stl, pcb_bottom_jack_only.stl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]
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2023-05-26 Fix a small LED flashing bug
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2023-07-23 Keyboard side hinge solution
    [pcb_bottom.scad, pcb_bottom_left_hinge.stl, pcb_bottom_right_hinge.stl]
2023-07-23 Turntable side hinge solution
    [TT_base_hinge.scad, TT_base_hinge.stl, TT_base_hinge_cover.stl]
2023-08-06 Option for hinge (fixed connection)
    [TT_base_hinge.scad, TT_base_hinge_150.stl, TT_base_hinge_170.stl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]
2023-08-30 Give up BLE and fix UF2 firmware
    [main.c]
2023-10-05 Bearing seat for hinge version
    [bearing_seat_6804_hinge.stl, bearing_seat_hinge.scad]
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2023-12-10 Big update (analog and effect mode removed)
    [TT_base_hinge.stl, TT_base_hinge_cover.stl, teeny_bearing.scad]
2024-01-03 Removal of confusion parts in PCB
    [iidx_pico.kicad_pcb, iidx_pico.kicad_sch, iidx_tt.kicad_pcb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]
2024-06-08 Turntable noise filtering and debouncing
    [main.c, turntable.c]
2024-09-09 PCB v1.3 fixes key "sticky-feel" problem
    [iidx_pico.kicad_pcb]
2024-09-09 Simple fix for earlier PCB versions.
2024-11-20 PCB v1.4 (sensor on board)
    [SM3B-SRSS-TB.step, SM4B-SRSS-TB.step, SM5B-SRSS-TB.step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]
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2024-12-03 CAD Artworks
    [beatmania_IIDX.dxf]
2024-12-06 PCB v1.41 (better 1615 LED footprint)
    [iidx_pico.kicad_pcb, iidx_pico.kicad_sch]
2024-12-12 Archive the old design
    [TT_assemble_6804.scad, TT_base.scad, TT_base_150.stl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]
2024-12-12 Refactored 3DPrint files
    [IIDX Pico_Jumbo - Base_1P.stl, IIDX Pico_Jumbo - Base_2P.stl, IIDX Pico_Jumbo - Panel.stl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]
2024-12-12 Re-arrange 3DPrint files
    [Keyboard - Base_1P.stl, Keyboard - Base_2P.stl, Keyboard - Panel.stl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]
2024-12-19 Add missing Bearing Seat
    [Turntable - Bearing Seat.stl]
2024-12-20 Fix not reporting button bug
    [main.c]
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2024-12-21 Use hex nut to fix disc seat and magnet seat
    [Turntable - Disc Seat.stl, Turntable - Magnet Seat.stl]
2025-01-09 Pico PCB v1.42 for lenient stabilizer cut
    [iidx_pico.kicad_pcb]
2025-01-09 Quick fix of Pico PCB v1.42
    [iidx_pico.kicad_pcb]
2025-01-11 Turntable STL finetune
    [Turntable Pico - Banner.stl, Turntable Pico - Base.stl, Turntable Teeny - Banner.stl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]
2025-01-15 Update missing teeny disc
    [Turntable Teeny - Disc.stl]
2025-01-16 Teeny PCB v1.31, finetune
    [iidx_teeny.kicad_pcb, iidx_teeny.kicad_sch]
2025-01-16 Latest finetuned STL files
    [Keyboard Teeny - Base_1P.stl, Keyboard Teeny - Base_2P.stl, Turntable 2B - Disc Seat.stl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]
2025-01-19 Reduce report jitter
2025-02-06 Jumbo Banner 1P and 2P
    [Turntable Jumbo - Banner 1P.stl, Turntable Jumbo - Banner 2P.stl, Turntable Jumbo - Banner.stl]
2025-02-09 Better pads and naming
    [Keyboard 1P - Base.stl, Keyboard 2P - Base.stl, Keyboard Teeny 1P - Base.stl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]
2025-02-09 PCB tolerance
    [Keyboard 1P - Base.stl, Keyboard 2P - Base.stl, Keyboard Teeny 1P - Base.stl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]
2025-02-09 Append previous PCB tolerance commit
    [Keyboard - Panel.stl, Keyboard Teeny - Panel.stl]
2025-02-21 Sensor board tolerance for TT base
    [Turntable Jumbo 1P - Base.stl, Turntable Jumbo 2B 1P - Base.stl, Turntable Jumbo 2B 2P - Base.stl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]
2025-02-22 Reinforce the bearing seat screws on base
    [Turntable Jumbo 1P - Base.stl, Turntable Jumbo 2B 1P - Base.stl, Turntable Jumbo 2B 2P - Base.stl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]
2025-02-23 Guide for new gen (eng first)
    [Turntable Jumbo - Disc.dxf, Turntable Pico - Disc.dxf]
2025-02-24 3D print files for Jumbo and Pico discs
    [Turntable Jumbo - Disc.stl, Turntable Pico - Disc.stl]
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2025-03-05 Refactoring for config and rgb led and level
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2025-08-09 Skip B8 on komani spoof mode
    [main.c]
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2025-08-16 Revert to 8bit turntable
    [main.c, turntable.c]
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2025-08-16 Hall effect switch support
    [Keyboard - Panel.stl, Keyboard 1P - Base.stl, Keyboard 2P - Base.stl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]
2025-09-02 Pico PCB v1.52, clearance for stab steel
    [iidx_pico.kicad_pcb]
2025-09-27 Keycaps optimized
    [Keycap - Choc V1.stl, Keycap - Choc V2.stl, Keycap - Pico Choc V1.stl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]
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2025-09-27 Fix live trigger setting issue
    [rgb.c]
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2025-11-17 Finetune cable teeth and banner edge
    [Keyboard 1P - Base.stl, Keyboard 2P - Base.stl, Keyboard DP - Base.stl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]
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2025-11-30 Fix E1 button lights
    [rgb.c]
2025-12-04 Fix HID axis direction
    [turntable.c]
2025-12-12 PCB Pico v1.53 (vref from vbus)
    [iidx_pico.kicad_pcb, iidx_pico.kicad_sch]
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2025-12-22 Fix HID light in hall LED modes
    [rgb.c]
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2026-01-03 PCB 1.54 (stab steel clearance)
    [iidx_pico.kicad_pcb]
2026-03-05 Enlarge the screw holes on discs
    [Turntable Jumbo - Disc.stl, Turntable Pico - Disc.stl, Turntable Teeny - Disc.stl]
2026-03-19 MT6701 support and some other fix
    [as5600.c, main.c, mt6701.c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]
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2026-03-21 Fix usb loop when no sensors
    [turntable.c]
2026-03-27 Update PCB v1.6 files missed
    [iidx_pico.kicad_pcb, iidx_pico.kicad_sch]
2026-04-19 Config versioning and factory reset at power-up
    [main.c]
2026-05-16 IIDX Itsy and IIDX Visa
    [Credit Button Assy (Groovy).step, EVQ-P1D05M.stp, IIDX Visa - Base.stl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]
2026-05-17 Two print options for IIDX Visa Base
    [IIDX Visa - Base.stl, IIDX Visa - Base_Insert.stl]
2026-05-23 More panel tolerance with keycap
    [Keyboard - Panel.stl]
2026-05-23 Countersunk screw option for IIDX Visa
    [IIDX Visa - Panel_Flat.stl]
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
